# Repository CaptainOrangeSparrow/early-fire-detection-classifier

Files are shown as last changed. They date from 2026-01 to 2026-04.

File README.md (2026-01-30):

# Early-fire-detection-classifier

## Description

This repository aims to detect fires at an early stage and classify the type of fire using sensor-fusion techniques and machine learning. The project is from the University of Texas at Austin's engineering senior design group Spring 2026.

## Things that are Good to Know

### GIT

Git on the jetson is setup using the SSH key route. Any git actions will not prompt a log in due to the stored SSH deploy key. Pushes will be recorded as have been made by the deploy key. Whoever is registered on the jetson's git config global user.email will show up as the user responsible of a commit at the time of commit.

To change the git config global user:

```git config --global user.email [git email here]```

When you want to do a COMMIT, change the git config global user email to your git email or sign your first name at the end of your commit message (For example add file -firstname).

Once you attempt to PUSH your changes, you will then be prompted with the following message to provide a passphrase for security (this passphrase is shared among the team members):

```Enter passphrase for key '/home/firedistinguisher/.ssh/id_ed25519':```

AFTER you finish pushing your changes and making edits, consider running the following command to clear the user.email environment variable so the next developer will be automatically reminded to provide their email when making their commits, thanks!

```git config --global --unset user.email```

-----

### SSH

To log onto the jetson from the ECE-LRC servers:

```ssh firedistinguisher@localhost -p 2000```

To log onto the jetson from the ECE-LRC servers with video forwarding:

```ssh firedistinguisher@localhost -p 2000 -Y```

To log onto the jetson from your laptop through the ECE-LRC servers to support web-streaming from local host on the jeston to your local browser:

```ssh ssh -J eid@mario.ece.utexas.edu -p 2000 firedistinguisher@localhost -L [port]:localhost:[port]```

- Replace [port] with the port number the web stream is hosted on or streaming to

-----

### CONDA Virtual Environment Manager

Available CONDA environments:

- base
- app
- appgui
- cameragui
- recording
- telemetry

Please do not modify the base environment.

-----

## Repository Structure

**I2C-testing**

This folder contains code to test accessing read-write functionality on the I2C bus using python smbus2 module for various connected devices including the ADC and HDC. Use i2cdetect -r to scan I2C busses for connected devices.

- ```basic-I2C.py``` sends read and write commands on the i2c bus
- ```ads1115-i2c.py``` is a class that reads values from the ads1115 modules
- ```hdc3022.py``` is a class that reads values from the hdc3022 temp and humidity sensor

Requires ```recording``` conda env.

-----

**audio-testing**

This folder contains code for testing the MAX98357A Audio Amp for producing audio from the jetson using the I2S protocol. 

- ```play-tone.py``` plays a sine wave for a specified duration and frequency
- ```play-wav.py``` plays a wav file

Requires ```recording``` conda env.

-----

**camera-gui**

This folder contains original python gui that was developed to play prerecorded mp4 files. A pyside 6 gui application is used to display the videos and interactive buttons.

- ```camera_gui.ipynb``` is the original python notebook that was used to develop the initial gui
- ```camera_gui.py``` is the python version of the ipynb notebook  
- ```test.txt``` is a test file

Requires ```cameragui``` conda env.

-----

**camera-testing**

This folder contains tools to view the raw camera streams for RGB and IR cameras. In particular, it contains code for the tc001. The raw camera streams open native openCV windows or host a web stream. NOTE: The tc001 code came from another repo leswright pythermalcam and contains some erroneous temperature decoding code. (That is fixed in the data recording camera module)

- ```readme```: This folder comes with its own readme. See readme for more details
- ```web-stream-camera.py``` is the web stream version of stream-camera.py. Note: to use the web-stream, the ssh port forwarding needs to be used. (See web stream ssh command above).

Requires ```cameragui``` conda env.

-----

**data-recording**

This is the main data recording software folder. Multi-modal data is recorded and streamed using either a pyside6 gui application, console only mode, or web stream application (recommended). Data is recorded at a default 25 FPS.

Recordings are saved to saved_recordings [dir] and test_recordings [dir] hold recordings that were taken just for testing and are kept for historical purposes.

- ```readme.txt```: This folder comes with its own readme. See readme for more details
- ```record.py``` is the main data recording script```
- ```utilities``` [dir] holds utility modules such as writers, web stream host server, html, javascript, etc. and other helpful utility code
- ```peripherals``` [dir] holds modules containing classes to read info and interact with connected external devices such as cameras and adcs.
- ```saved_recordings``` [dir] holds saved recordings
- ```test_recordings``` [dir] holds test recordings
- ```clear_Saved_to_test.py``` is a helper script to move all recordings in saved_recordings to test_recordings
- ```gstreamer_test.py``` is a helper script to test using gstreamer to run nvidia hardware optimized camera frames
- ```verify-frame-count.py``` is a helper script to count the number of frames in every mp4 file in a specified directory (does not search child directories)

Requires ```recording``` conda env.

-----

**downloads**

The purpose of this folder is to store files in transit (Files that needed to be copied over into or exported out of the jeston).

-----

**stream-camera-gui**

This folder contains files to stream both RGB and IR camera feeds simultaneously with a more custom gui in a pyside6 application

- ```readme.txt```: This folder comes with its own readme. See readme for more details. This readme has details for the rest of the components in the folder and therefore the other contents in the folder won't be listed again here.

Requires ```appgui``` conda env.

-----

**telemetry-display**

This folder contains files to stream data to a ST7735 LCD display.

Requires ```telemetry``` conda env.

-----

**test-files**

This folder contains miscellaneous test files.

----

## Additional Notes

Thanks, add anything other considerations here if need be.

Michael

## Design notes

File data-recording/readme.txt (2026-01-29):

===================
Readme.txt

record.py is the main recording script. 
Activate the conda env named recording.
Do python record.py -h for more details about its params

Note: If --web-preview is used, to view the web app on your local browser at localhost:5000, 
	you need to have ssh-ed in with the following or open another terminal and do another ssh:

	ssh -J eid@mario.ece.utexas.edu -p 2000 firedistinguisher@localhost -L 5000:localhost:5000 -Y

	If you get a bunch of channel open failed, that is the browser trying to connect when the script
	is not running. So when not using the script, close the browser tab if you want to remove that message.

Recommended use: python record.py [name] --no-gui --web-preview (--view-only if not recording)

You can change whether the thermal camera frames use Min-Max Normalization or Fixed Ranged Normalization by changing
a setting on Line 147 in peripherals/cameras.py

Directories:
- saved_recordings[dir] is the default location that new recordings are saved.
- peripherals[dir] and utilities[dir] are extra helper python modules to help record.py function

Recordings are saved in the following format:
- New directory created and named appropriately
- .mp4 for rgb camera
- .mp4 for ir camera
- .csv for all channels of the ADC
- .json to hold metadatda
- .npz files for raw thermal data (stored in raw_ir [directory])

- The rows of the csv file should match up with the frames of the mp4 files
- The new directory created will have the name, desired fps, date, index, unix time, and time.
  The index increments when there is a recording with the same date in the same destination directory
- The arrays in the npz files store the raw 192x256 data in row major order (top left corner is 0,0, +y axis down, +x axis right). Frame number is also stored along with the arrays

Other scripts:
- clear_saved_to_test.py is a script that moves all the recordings in the saved_recordings directory into the test_recordings directory.
- gstreamer-test.py is a script to test gstreamer pipelines when opening camera devices with python scripts.
- verify-frame-count.py counts the number of frames of all .mp4 files in a given directory.

-Michael

===================

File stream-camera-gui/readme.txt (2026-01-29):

===================

constants.py
- file to store global constants for easy access and so it is also accessible from all other modules/files

gui.py
- integrated IR camera stream with Moby's original gui

gui-new.py
- integrated both IR and RGB camera streams with a new gui layout

peripherals [dir]
- folder containing python modules to inteface sensors with the gui

	cameras.py
	- contains classes for RBG and IR cameras to be intialized and used elsewhere with functions to read frames.
	  supports multiple things accessing it at once.

gui-assets [dir]
- folder containing resources to support the gui such as downloaded fonts, images, etc.

saved_recordings [dir]
- folder containing saved recordings to be played back in the gui.
  future recordings could be saved here from the gui.

===================

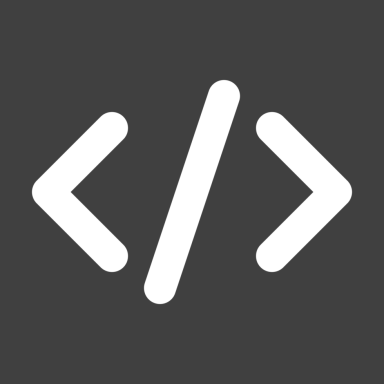
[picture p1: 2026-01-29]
stream-camera-gui/gui-assets/images/Nav-Code.png

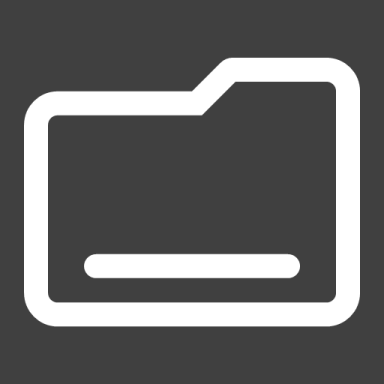
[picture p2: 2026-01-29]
stream-camera-gui/gui-assets/images/Nav-Saves.png

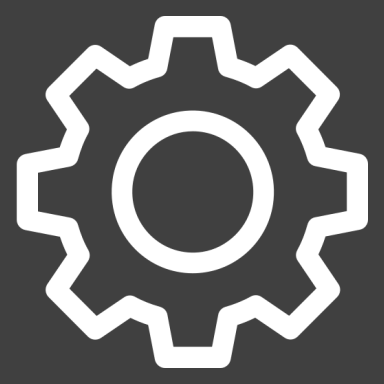
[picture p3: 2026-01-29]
stream-camera-gui/gui-assets/images/Nav-Settings.png

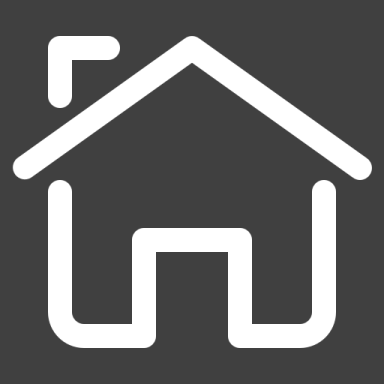
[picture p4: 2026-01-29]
stream-camera-gui/gui-assets/images/Nav-Home.png

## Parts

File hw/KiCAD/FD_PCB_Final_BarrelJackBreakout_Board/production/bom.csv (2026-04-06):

Designator | Footprint | Quantity | Value | LCSC Part #
H3, H4, H5, H6 | MountingHole_4_40 | 4 | ~
J1 | BarrelJack_Wuerth_6941xx301002 | 1 | Barrel_Jack_Switch
J24 | PinHeader_1x02_P2.54mm_Vertical | 1 | Conn_01x02

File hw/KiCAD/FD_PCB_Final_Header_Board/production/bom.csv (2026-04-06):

Designator | Footprint | Quantity | Value | LCSC Part #
C1, C2, C3 | CP_Radial_Tantal200mil | 3 | 220u
C16 | C_Axial_200mil | 1 | 10u
C17, C18, C19, C20 | 0805 | 4 | 0.1u
C6 | CP_Radial_Tantal200mil | 1 | 47u
H17, H18, H19, H20 | MountingHole_4_40 | 4 | ~
J10, J11, J25, J7 | PinHeader_1x02_P2.54mm_Vertical | 4 | Conn_01x02
J12 | JST_PH_B2B-PH-K_1x02_P2.00mm_Vertical | 1 | Conn_01x02
J2 | PinHeader_2x12_P2.54mm_Vertical | 1 | Conn_02x12_Odd_Even
J4 | PinHeader_2x20_P2.54mm_Vertical | 1 | Conn_02x20_Odd_Even
J5 | PinHeader_2x10_P2.54mm_Vertical | 1 | Conn_02x10_Odd_Even
J6 | PinHeader_1x07_P2.54mm_Vertical | 1 | Conn_01x07
M1, M2 | PinHeader_1x03_P2.54mm_Vertical | 2 | Motor_Servo
R2 | 0805 | 1 | 100k
TP11, TP4, TP8 | TestPoint_Loop_D3.50mm_Drill1.4mm_Beaded | 3 | TestPoint

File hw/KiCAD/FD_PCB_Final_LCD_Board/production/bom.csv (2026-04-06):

Designator | Footprint | Quantity | Value | LCSC Part #
H10, H7, H8, H9 | MountingHole_4_40 | 4 | ~
J3 | PinHeader_2x12_P2.54mm_Vertical | 1 | Conn_02x12_Odd_Even
J9 | PinHeader_1x16_P2.54mm_Vertical | 1 | Conn_01x16
R1, R3, R4 | 0805 | 3 | 1k
SW1, SW2, SW3 | SW_PUSH_6mm | 3 | SW_Push
TP1, TP10, TP12, TP13, TP14, TP2, TP3, TP46, TP5, TP6, TP7, TP9 | TestPoint_Loop_D3.50mm_Drill1.4mm_Beaded | 12 | TestPoint

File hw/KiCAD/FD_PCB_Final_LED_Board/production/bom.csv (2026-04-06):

Designator | Footprint | Quantity | Value | LCSC Part #
D1 | LED_D5.0mm | 1 | +5V PWR
D2 | LED_D5.0mm | 1 | +3V3 PWR
D3 | LED_D5.0mm | 1 | LED_1
D4 | LED_D5.0mm | 1 | LED_2
H1, H2 | MountingHole_4_40 | 2 | ~
J21 | PinHeader_1x08_P2.54mm_Vertical | 1 | Conn_01x08

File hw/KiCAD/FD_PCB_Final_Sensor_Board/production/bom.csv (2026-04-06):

Designator | Footprint | Quantity | Value | LCSC Part #
C10, C11, C12, C13, C14, C15, C7, C8 | 0805 | 8 | 1u
C21, C4, C5 | CP_Radial_Tantal200mil | 3 | 4.7u
C9 | CP_Radial_Tantal200mil | 1 | 47u
D5 | LED_D5.0mm | 1 | +5V PWR
D6 | LED_D5.0mm | 1 | +3V3 PWR
FB1, FB2, FB3, FB4 | 0603 | 4 | FerriteBead
H11, H12, H13, H14, H15, H16 | MountingHole_4_40 | 6 | ~
J13 | PinHeader_2x10_P2.54mm_Vertical | 1 | Conn_02x10_Odd_Even
J14 | PinHeader_1x04_P2.54mm_Vertical | 1 | MQ-4 Gas Sensor
J15 | PinHeader_1x04_P2.54mm_Vertical | 1 | MQ-7 Gas Sensor
J16 | PinHeader_1x04_P2.54mm_Vertical | 1 | MQ-138 Gas Sensor
J17 | PinHeader_1x04_P2.54mm_Vertical | 1 | KY-026 Flame Sensor
J18 | PinHeader_1x10_P2.00mm_Vertical | 1 | Conn_01x10
J19 | PinHeader_1x05_P2.00mm_Vertical | 1 | Conn_01x05
J20 | PinHeader_1x06_P2.54mm_Vertical | 1 | HDC3022
J22 | PinHeader_1x05_P2.54mm_Vertical | 1 | MiCS-6814
J23 | PinHeader_1x02_P2.54mm_Vertical | 1 | Conn_01x02
J8 | PinHeader_1x08_P2.54mm_Vertical | 1 | Conn_01x08
R10, R11, R22, R23, R24, R9 | 0805 | 6 | 18k
R12, R13, R14, R25, R26, R27 | 0805 | 6 | 33k
R15, R16, R17, R18, R28, R29, R30, R31 | 0805 | 8 | 10k
R19 | 0805 | 1 | 560k
R20 | 0805 | 1 | 150k
R21 | 0805 | 1 | 15k
R32, R33 | 0805 | 2 | 0
R34, R7 | 0805 | 2 | 2k
R35, R6, R8 | 0805 | 3 | 1k
R5 | 0805 | 1 | 330
TP15, TP16, TP17, TP18, TP19, TP20, TP21, TP22, TP23, TP24, TP25, TP26, TP27, TP28, TP29, TP30, TP31, TP32, TP33, TP34, TP35, TP36, TP37, TP38, TP39, TP40, TP41, TP42, TP43, TP44, TP45 | TestPoint_Loop_D3.50mm_Drill1.4mm_Beaded | 31 | TestPoint
U1, U4 | TSSOP-10_3x3mm_P0.5mm | 2 | ADS1115IDGS
U2, U3 | DIP-8_W7.62mm_LongPads | 2 | OPA2350

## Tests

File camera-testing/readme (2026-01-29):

===================
tc001 [dir]
- Code to view TC001 camera

stream-camera.py
- stream any video device to an opencv window

venv [dir]
- Python virtual environment

===================

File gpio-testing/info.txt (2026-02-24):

(recording) firedistinguisher@jetsonnano:~/projects/early-fire-detection-classifier/gpio-testing$ sudo -E /home/firedistinguisher/miniconda3/envs/recording/bin/python jetson-gpio.py
/home/firedistinguisher/miniconda3/envs/recording/lib/python3.10/site-packages/Jetson/GPIO/gpio_cdev.py:361: UserWarning:
[WARNING] User requested output for channel "15", but it is set to input in pinmux. For more information on resolving this, please see
https://docs.nvidia.com/jetson/archives/r36.3/DeveloperGuide/HR/JetsonModuleAdaptationAndBringUp/JetsonOrinNxNanoSeries.html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

This can be resolved *temporarily* (until next restart) by running:
    sudo busybox devmem 0x2440020 w 0x5

  warnings.warn(

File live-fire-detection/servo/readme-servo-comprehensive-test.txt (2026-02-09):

# Run all tests
python3 servo-comprehensive-test.py

# Run specific test suite
python3 servo-comprehensive-test.py basic
python3 servo-comprehensive-test.py linear
python3 servo-comprehensive-test.py patterns

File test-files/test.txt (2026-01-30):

MC test 01-30-2026
MC test 01-30-2026 at 3:03am

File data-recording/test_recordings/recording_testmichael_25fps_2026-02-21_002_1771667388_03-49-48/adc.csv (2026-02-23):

frame_idx | t_sample_perf_counter | t_reg_frame | t_ir_frame | t_adc_sweep | adc_sweep_dt_s | adc0_ch0 | adc0_ch1 | adc0_ch2 | adc0_ch3 | adc1_ch0 | adc1_ch1 | adc1_ch2 | adc1_ch3 | ir_min | ir_max | ir_avg | ir_center | t_hdc_sample | hdc_temp | hdc_humidity | t_sen0219_sample | co2_ppm | t_ze07co_sample | co_ppm
0 | 6463.558493449 | 6463.533839089 | 6463.547695484 | 6463.551141031 | 0.034862 | 1606 | 1768 | 5457 | 24379 | -711 | -763 | -763 | 4267 | 27.725000000000023 | 36.35000000000002 | 28.524509684244833 | 28.225000000000023 | 6463.546819169 | 27.558175020981153 | 41.031509880216674 | 1771667391.322329283 | 526 | 1771667391.341055393 | 0.5
1 | 6463.588732046 | 6463.568426044 | 6463.547695484 | 6463.551141031 | 0.034862 | 1606 | 1768 | 5457 | 24379 | -711 | -763 | -763 | 4267 | 27.725000000000023 | 36.35000000000002 | 28.524509684244833 | 28.225000000000023 | 6463.578676632 | 27.536812390325778 | 41.03608758678568 | 1771667391.352990150 | 526 | 1771667391.373149633 | 0.5
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

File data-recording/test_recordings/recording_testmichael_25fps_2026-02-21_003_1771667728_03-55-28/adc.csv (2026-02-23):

frame_idx | t_sample_perf_counter | t_reg_frame | t_ir_frame | t_adc_sweep | adc_sweep_dt_s | adc0_ch0 | adc0_ch1 | adc0_ch2 | adc0_ch3 | adc1_ch0 | adc1_ch1 | adc1_ch2 | adc1_ch3 | ir_min | ir_max | ir_avg | ir_center | t_hdc_sample | hdc_temp | hdc_humidity | t_sen0219_sample | co2_ppm | t_ze07co_sample | co_ppm
0 | 6804.402423980 | 6804.381755624 | 6804.384136805 | 6804.385002660 | 0.031725 | 1651 | 1863 | 5503 | 24334 | -710 | -755 | -759 | 4394 | 25.412500000000023 | 33.10000000000002 | 26.90463790893557 | 27.225000000000023 | 6804.379380364 | 27.536812390325778 | 41.361104753185316 | 6804.377583918 | 534 | 6804.364221313 | 0.5
1 | 6804.453322949 | 6804.411479487 | 6804.426995689 | 6804.429996645 | 0.044958 | 1656 | 1869 | 5522 | 24369 | -712 | -764 | -765 | 4422 | 25.412500000000023 | 33.10000000000002 | 26.9053728739421 | 27.225000000000023 | 6804.431103012 | 27.536812390325778 | 41.361104753185316 | 6804.405732263 | 534 | 6804.402953931 | 0.5
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

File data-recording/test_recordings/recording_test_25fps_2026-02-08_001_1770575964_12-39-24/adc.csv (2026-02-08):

frame_idx | t_sample_perf_counter | t_reg_frame | t_ir_frame | t_adc_sweep | adc_sweep_dt_s | adc0_ch0 | adc0_ch1 | adc0_ch2 | adc0_ch3 | adc1_ch0 | adc1_ch1 | adc1_ch2 | adc1_ch3 | ir_min | ir_max | ir_avg | ir_center | hdc_temp | hdc_humidity
0 | 27962.986315563 | 27962.952133460 | 27962.978301277 | 27962.934848659 | 0.036480 | 2469 | 3185 | 6495 | 25611 | -161 | -176 | -181 | 4617 | 26.037500000000023 | 37.72500000000002 | 32.32694905598959 | 36.47500000000002 | 27962.979030931 | 29.811932555123207 | 43.96124208438239
1 | 27963.008805351 | 27962.986508273 | 27962.978301277 | 27962.993043539 | 0.058148 | 2471 | 3189 | 6505 | 25616 | -164 | -178 | -179 | 4612 | 26.037500000000023 | 37.72500000000002 | 32.32694905598959 | 36.47500000000002 | 27963.003830516 | 29.79056992446783 | 43.95208667124437
2 | 27963.053611290 | 27963.020980625 | 27963.017713072 | 27963.044436586 | 0.051330 | 2474 | 3189 | 6509 | 25627 | -175 | -173 | -178 | 4605 | 25.975000000000023 | 37.72500000000002 | 32.33729960123702 | 36.47500000000002 | 27963.035914924 | 29.811932555123207 | 43.947508964675364
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

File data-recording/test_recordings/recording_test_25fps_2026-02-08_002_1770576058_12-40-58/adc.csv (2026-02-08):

frame_idx | t_sample_perf_counter | t_reg_frame | t_ir_frame | t_adc_sweep | adc_sweep_dt_s | adc0_ch0 | adc0_ch1 | adc0_ch2 | adc0_ch3 | adc1_ch0 | adc1_ch1 | adc1_ch2 | adc1_ch3 | ir_min | ir_max | ir_avg | ir_center | hdc_temp | hdc_humidity
0 | 28056.960129481 | 28056.936664305 | 28056.931167950 | 28056.937265635 | 0.031993 | 2591 | 3398 | 6693 | 25854 | -172 | -177 | -182 | 4616 | 32.22500000000002 | 43.41250000000002 | 38.21861801147463 | 41.47500000000002 | 28056.940258524 | 29.83329518577858 | 44.83710994125277
1 | 28056.998672193 | 28056.967953042 | 28056.966692364 | 28056.975335789 | 0.038035 | 2590 | 3399 | 6696 | 25861 | -175 | -181 | -184 | 4611 | 32.22500000000002 | 43.41250000000002 | 38.220950063069665 | 41.47500000000002 | 28056.988160329 | 29.83329518577858 | 44.84321355001145
2 | 28057.026890374 | 28057.003495856 | 28057.005752531 | 28057.015128809 | 0.039745 | 2593 | 3400 | 6696 | 25863 | -167 | -180 | -183 | 4588 | 32.22500000000002 | 43.41250000000002 | 38.22927500406905 | 41.47500000000002 | 28057.020738032 | 29.811932555123207 | 44.855420767528805
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

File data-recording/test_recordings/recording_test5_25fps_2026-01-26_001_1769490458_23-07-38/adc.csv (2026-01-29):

frame_idx | t_sample_perf_counter | t_reg_frame | t_ir_frame | t_adc_sweep | adc_sweep_dt_s | adc0_ch0 | adc0_ch1 | adc0_ch2 | adc0_ch3 | adc1_ch0 | adc1_ch1 | adc1_ch2 | adc1_ch3 | ir_min | ir_max | ir_avg | ir_center
0 | 442818.211030183 | 442818.190247730 | 442818.180236602 | 442818.171502153 | 0.027324 | 1898 | 304 | 155 | 4710 | 4661 | 4365 | 4934 | 5110 | 27.100000000000023 | 40.72500000000002 | 32.4667793273926 | 32.60000000000002
1 | 442818.246832144 | 442818.225938651 | 442818.215313183 | 442818.208507449 | 0.036987 | 1896 | 307 | 503 | 4763 | 4716 | 4454 | 4418 | 5558 | 27.100000000000023 | 40.72500000000002 | 32.47111536661788 | 32.60000000000002
2 | 442818.282644058 | 442818.259110741 | 442818.254787677 | 442818.250575461 | 0.042018 | 1898 | 304 | 160 | 4693 | 4585 | 4819 | 5297 | 4654 | 26.975000000000023 | 40.72500000000002 | 32.47264887491866 | 32.60000000000002
3 | 442818.329053374 | 442818.290890920 | 442818.297281932 | 442818.293457558 | 0.042829 | 1896 | 306 | 470 | 4750 | 4730 | 4266 | 5281 | 4606 | 26.975000000000023 | 40.72500000000002 | 32.47873458862307 | 32.60000000000002
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

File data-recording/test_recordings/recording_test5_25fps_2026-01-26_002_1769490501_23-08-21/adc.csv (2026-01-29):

frame_idx | t_sample_perf_counter | t_reg_frame | t_ir_frame | t_adc_sweep | adc_sweep_dt_s | adc0_ch0 | adc0_ch1 | adc0_ch2 | adc0_ch3 | adc1_ch0 | adc1_ch1 | adc1_ch2 | adc1_ch3 | ir_min | ir_max | ir_avg | ir_center
0 | 442860.877039174 | 442860.863238310 | 442860.856792920 | 442860.862135710 | 0.032157 | 1901 | 307 | 75 | 4676 | 4719 | 5124 | 4641 | 4051 | 26.850000000000023 | 39.35000000000002 | 31.3154070536296 | 31.350000000000023
1 | 442860.910614833 | 442860.895155845 | 442860.890751302 | 442860.898824990 | 0.036654 | 1904 | 306 | 132 | 4739 | 4781 | 4745 | 3923 | 4788 | 26.850000000000023 | 39.41250000000002 | 31.32144444783529 | 31.287500000000023
2 | 442860.951321582 | 442860.931171905 | 442860.929185715 | 442860.938804406 | 0.039938 | 1902 | 305 | 410 | 4756 | 4651 | 4131 | 5147 | 4890 | 26.850000000000023 | 39.41250000000002 | 31.323936716715536 | 31.287500000000023
3 | 442860.993825687 | 442860.963849701 | 442860.969279051 | 442860.973593769 | 0.034756 | 1901 | 306 | 51 | 4707 | 4589 | 4659 | 5169 | 4676 | 26.850000000000023 | 39.35000000000002 | 31.325697835286462 | 31.350000000000023
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

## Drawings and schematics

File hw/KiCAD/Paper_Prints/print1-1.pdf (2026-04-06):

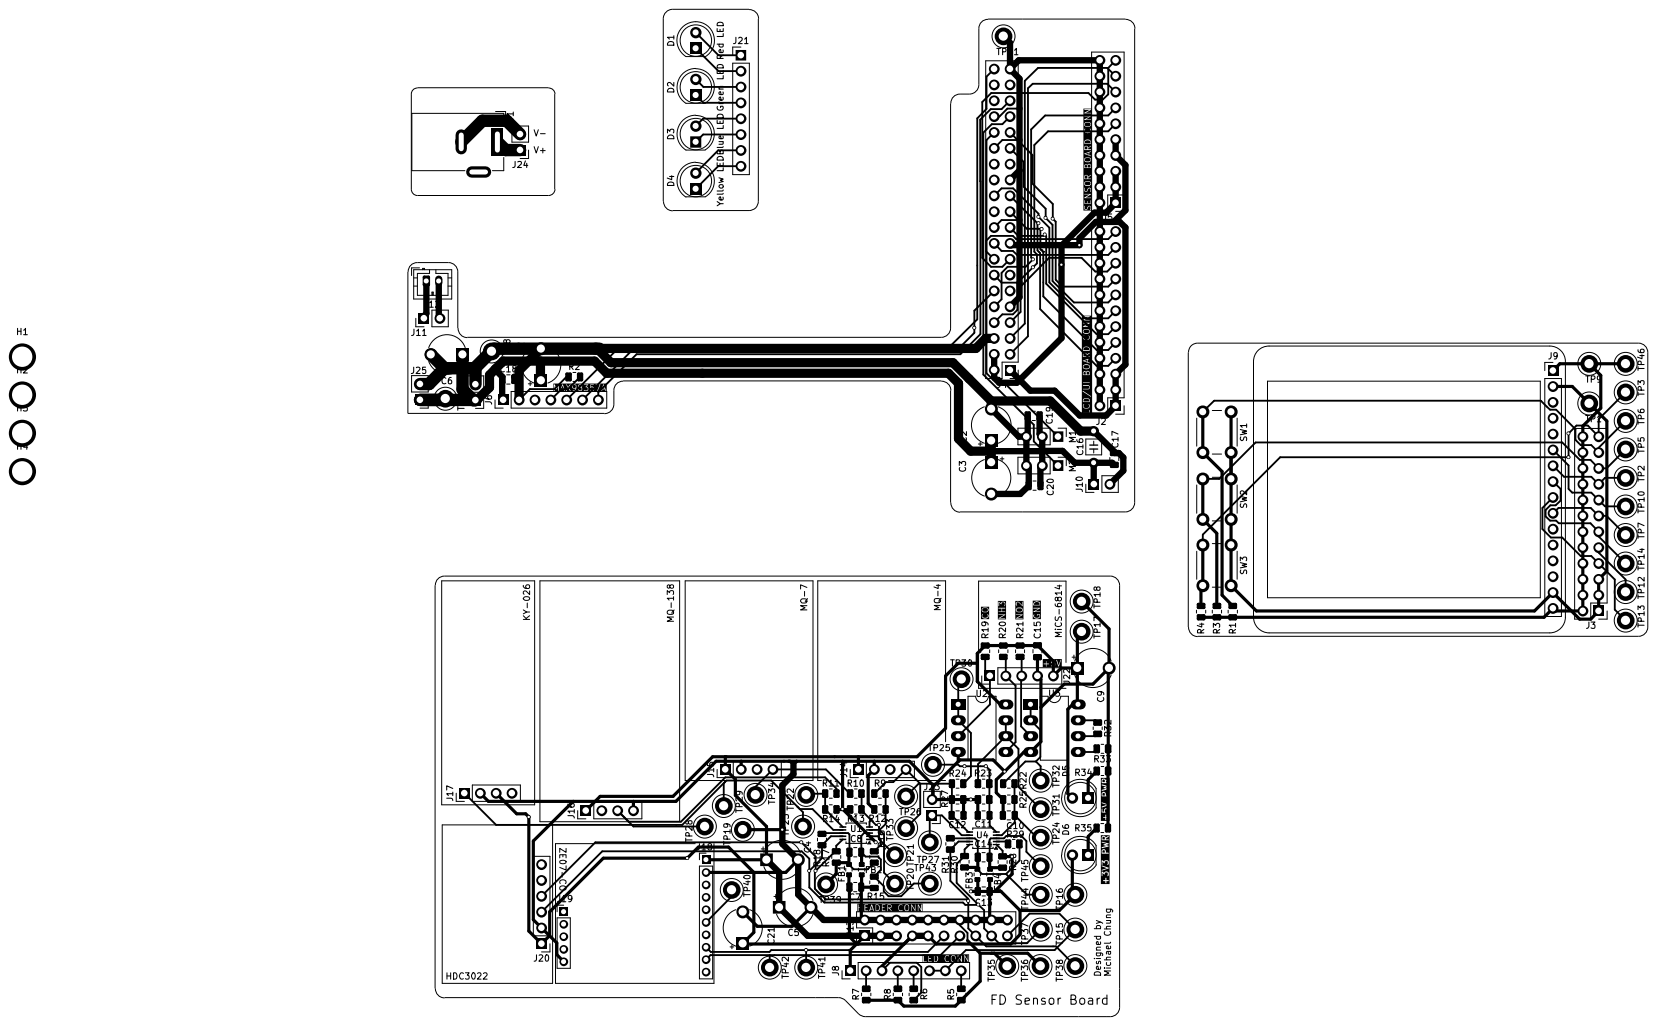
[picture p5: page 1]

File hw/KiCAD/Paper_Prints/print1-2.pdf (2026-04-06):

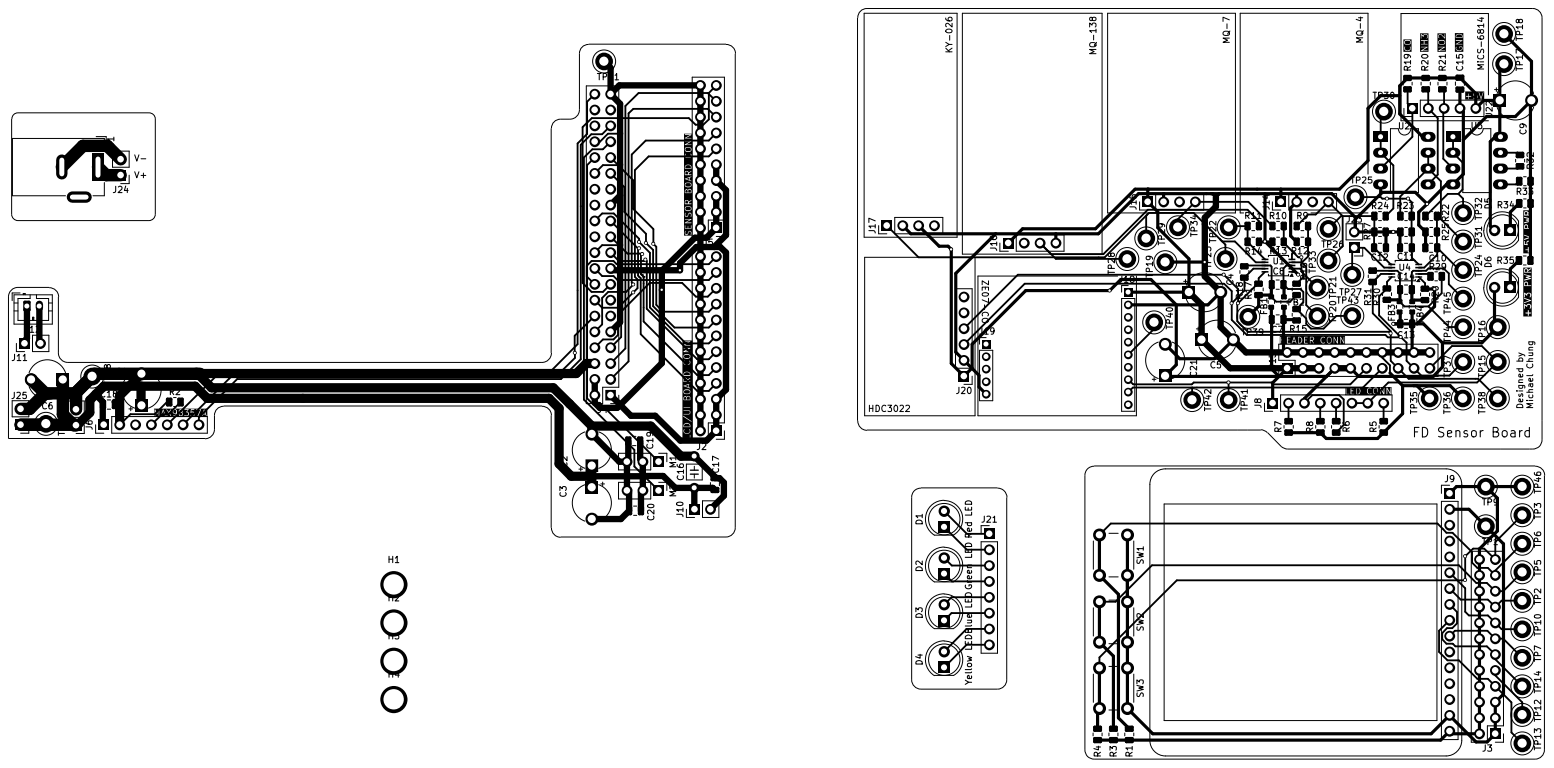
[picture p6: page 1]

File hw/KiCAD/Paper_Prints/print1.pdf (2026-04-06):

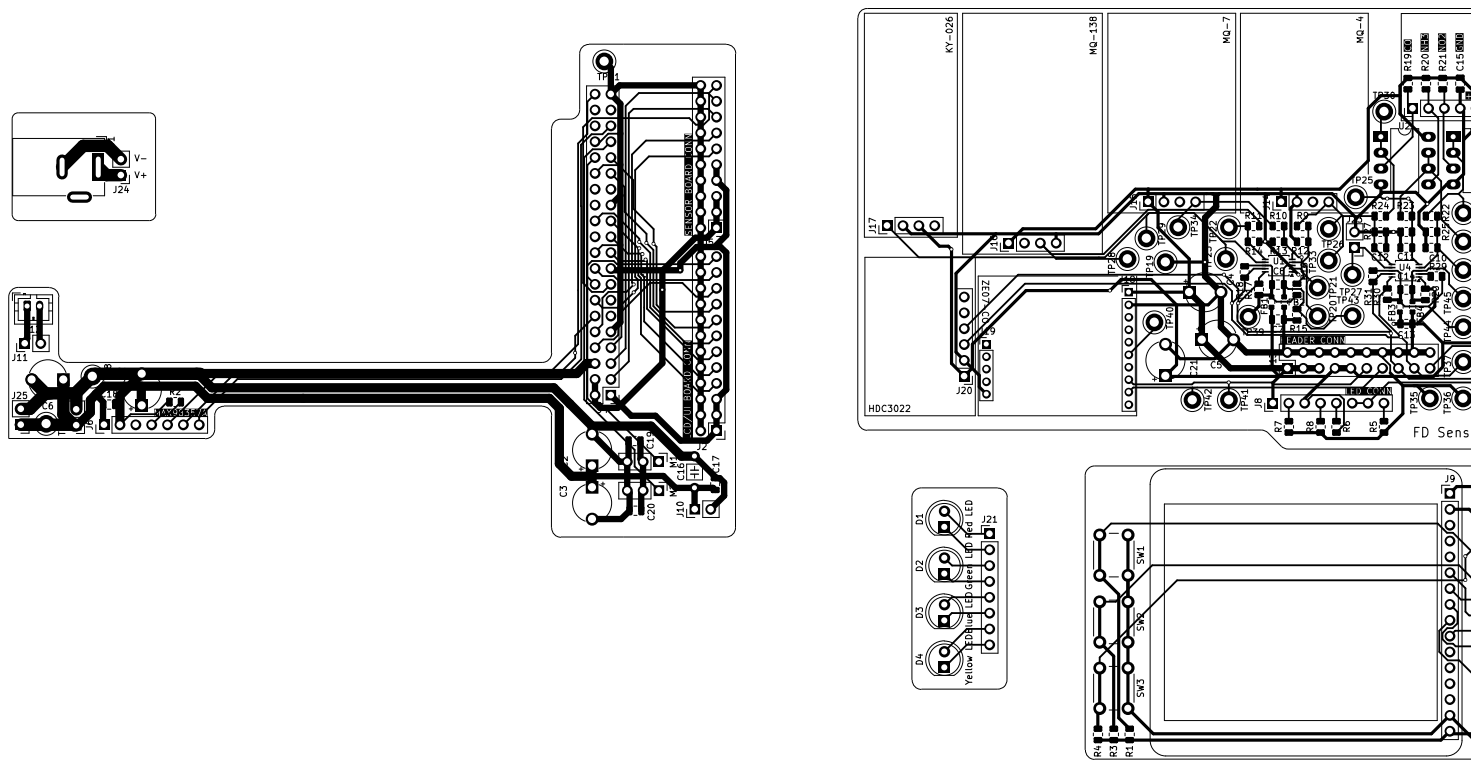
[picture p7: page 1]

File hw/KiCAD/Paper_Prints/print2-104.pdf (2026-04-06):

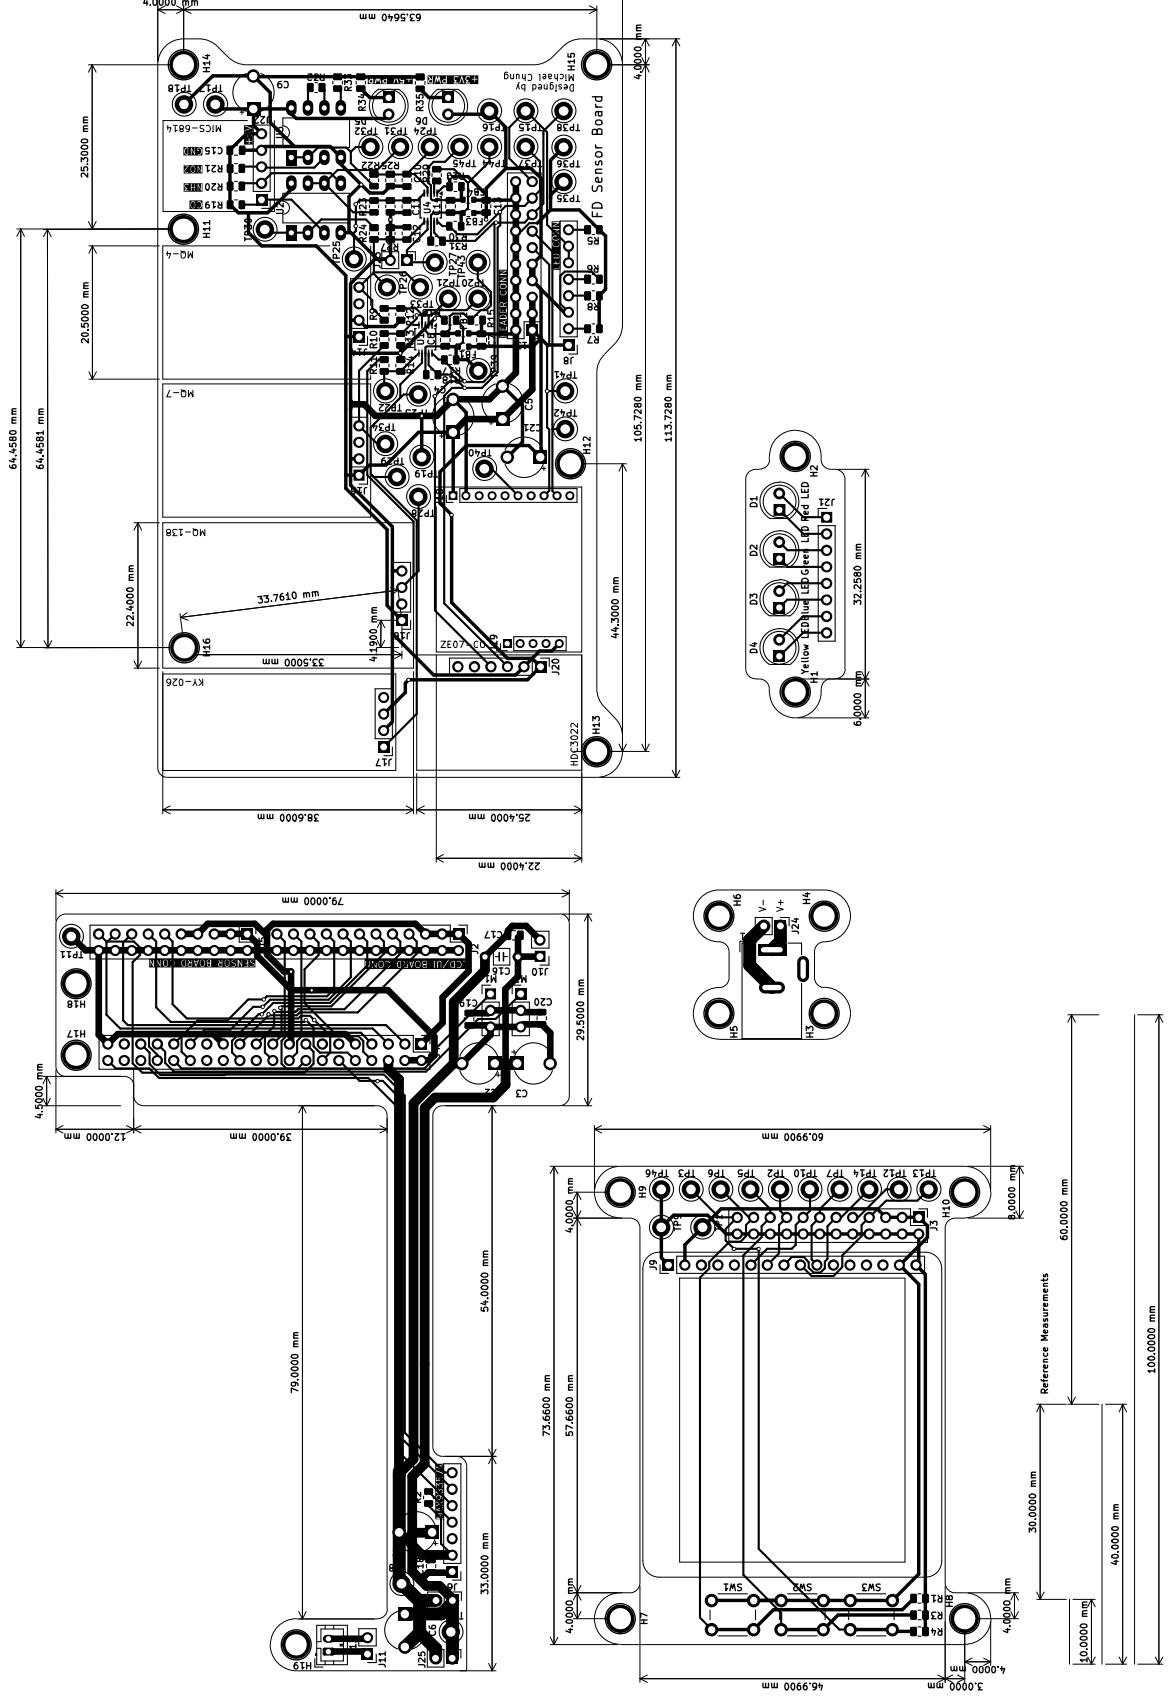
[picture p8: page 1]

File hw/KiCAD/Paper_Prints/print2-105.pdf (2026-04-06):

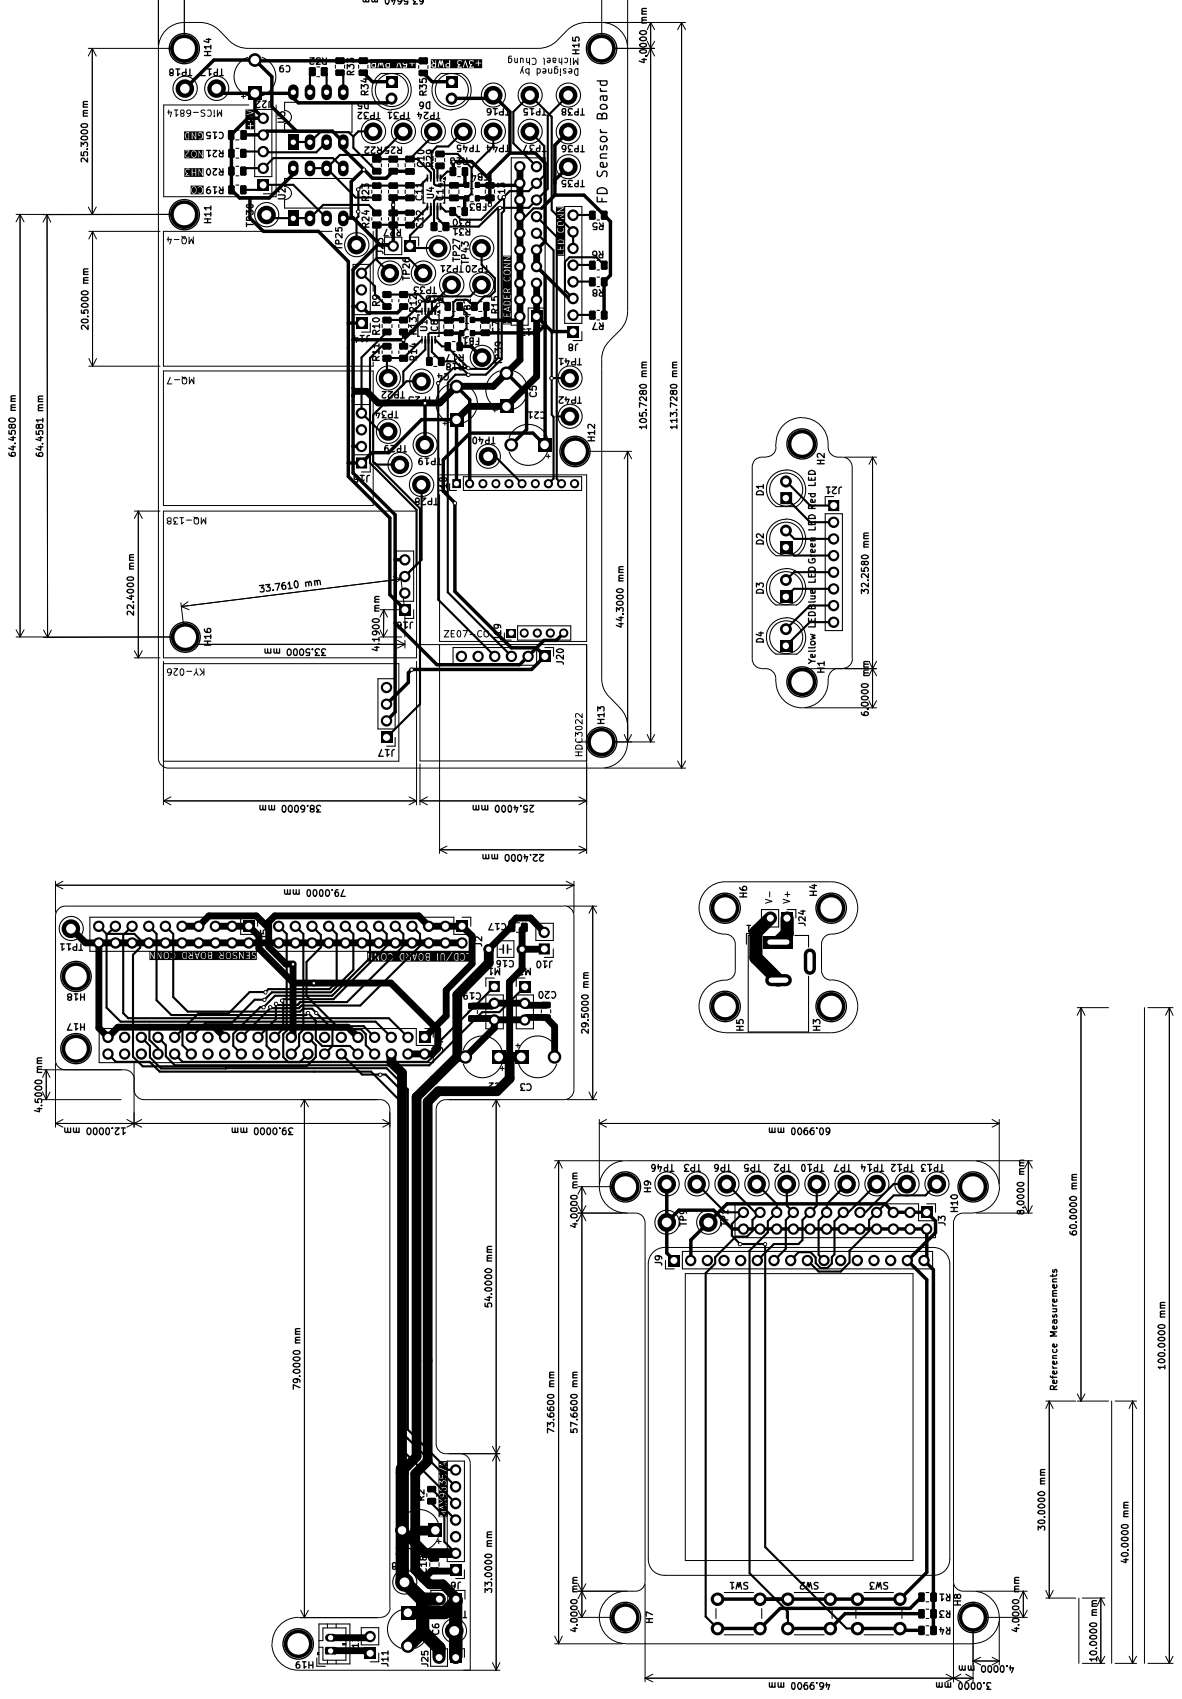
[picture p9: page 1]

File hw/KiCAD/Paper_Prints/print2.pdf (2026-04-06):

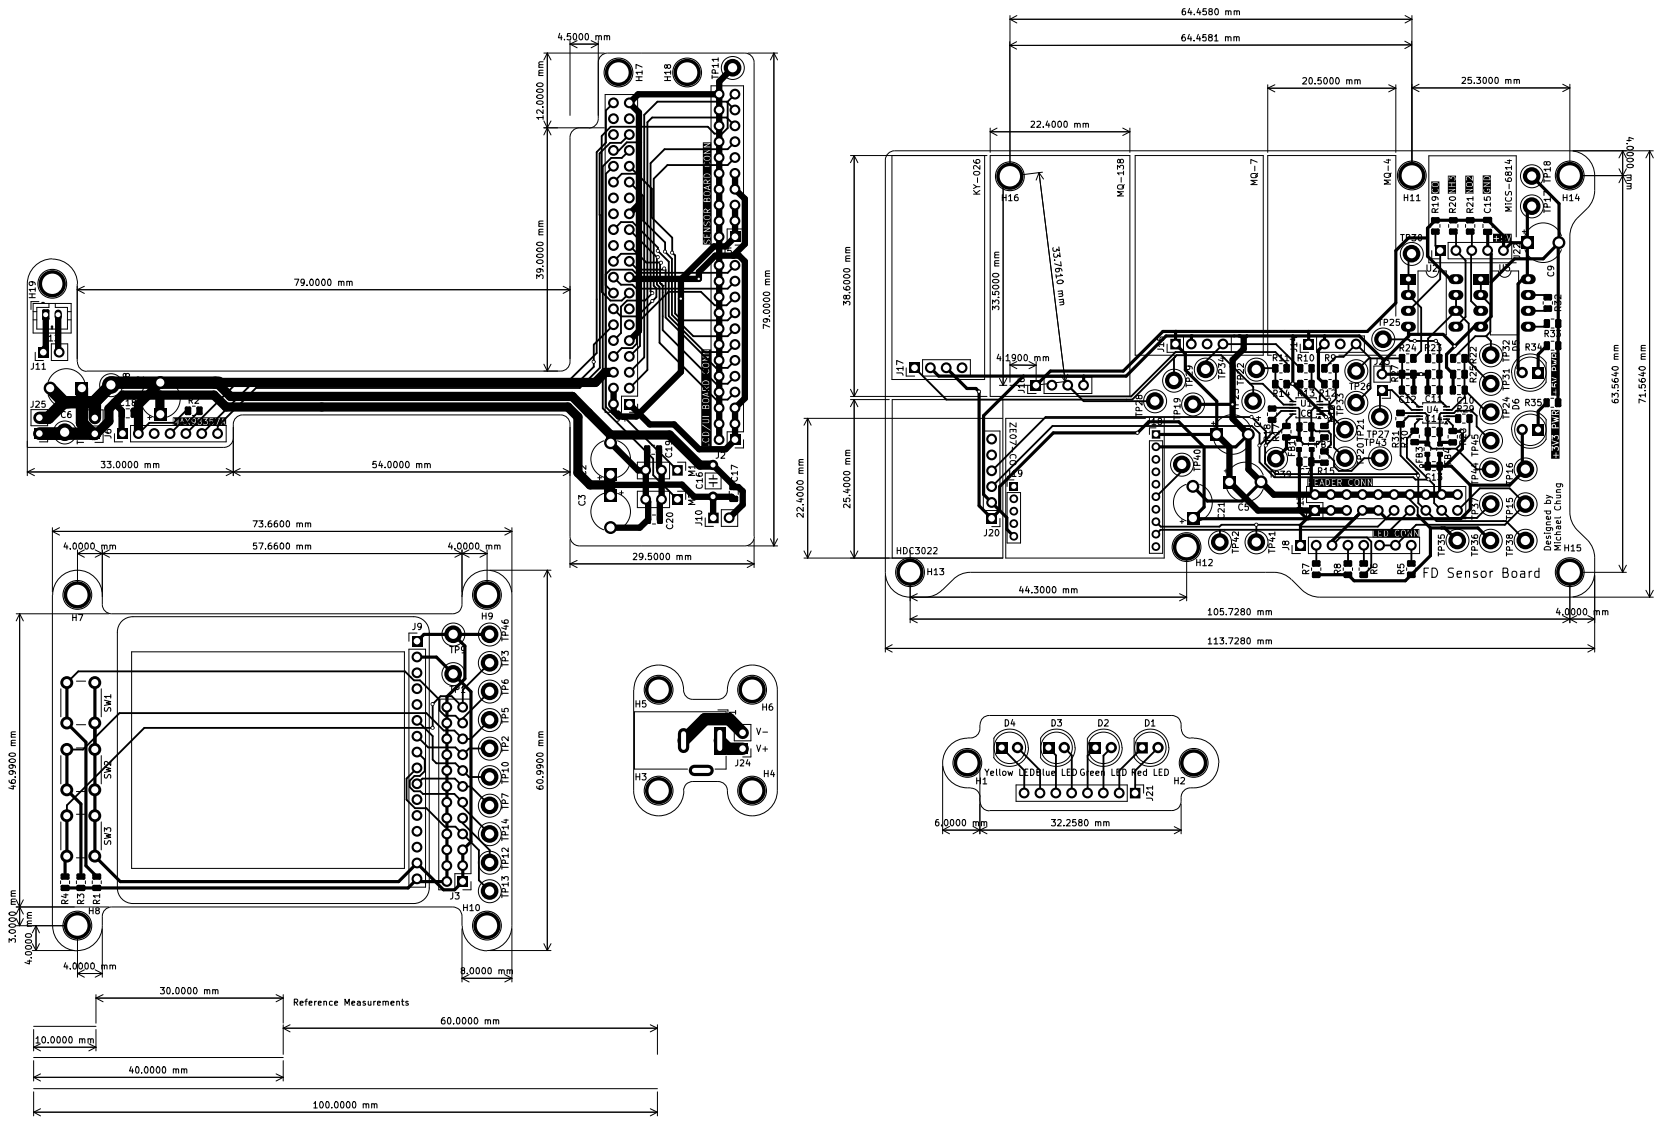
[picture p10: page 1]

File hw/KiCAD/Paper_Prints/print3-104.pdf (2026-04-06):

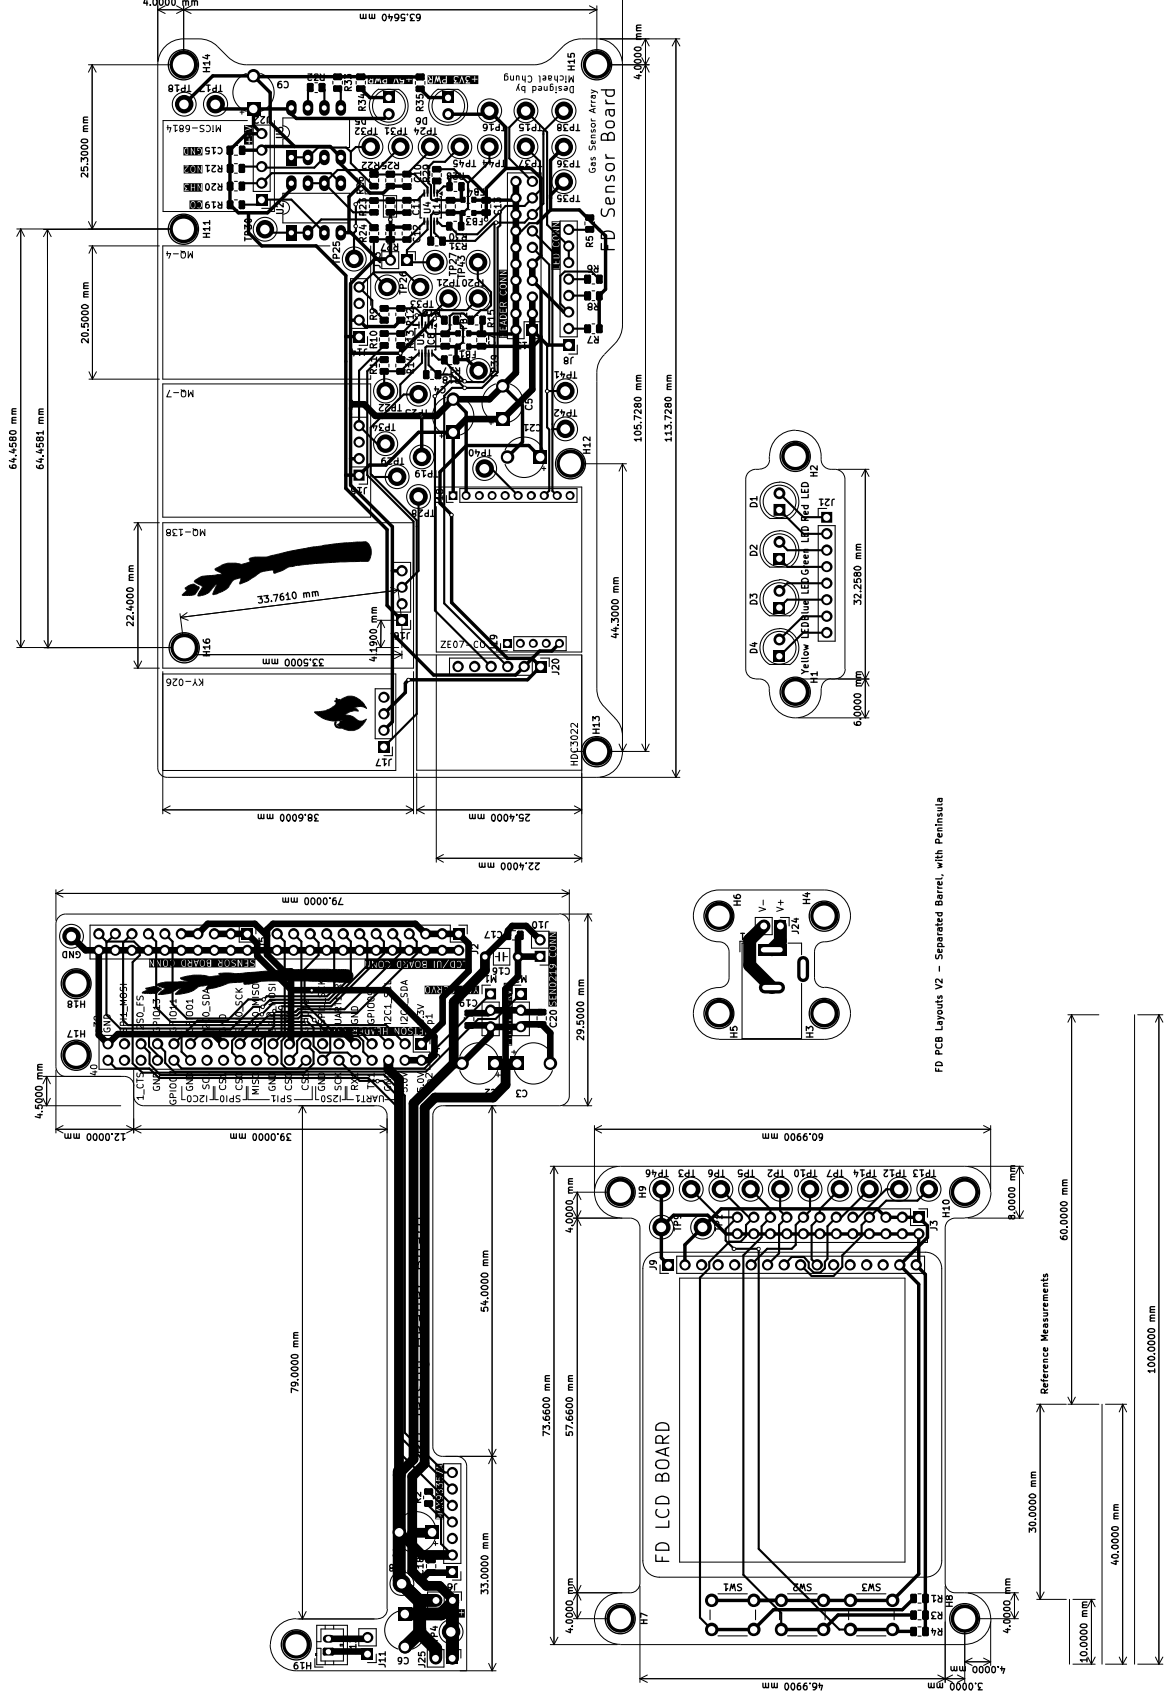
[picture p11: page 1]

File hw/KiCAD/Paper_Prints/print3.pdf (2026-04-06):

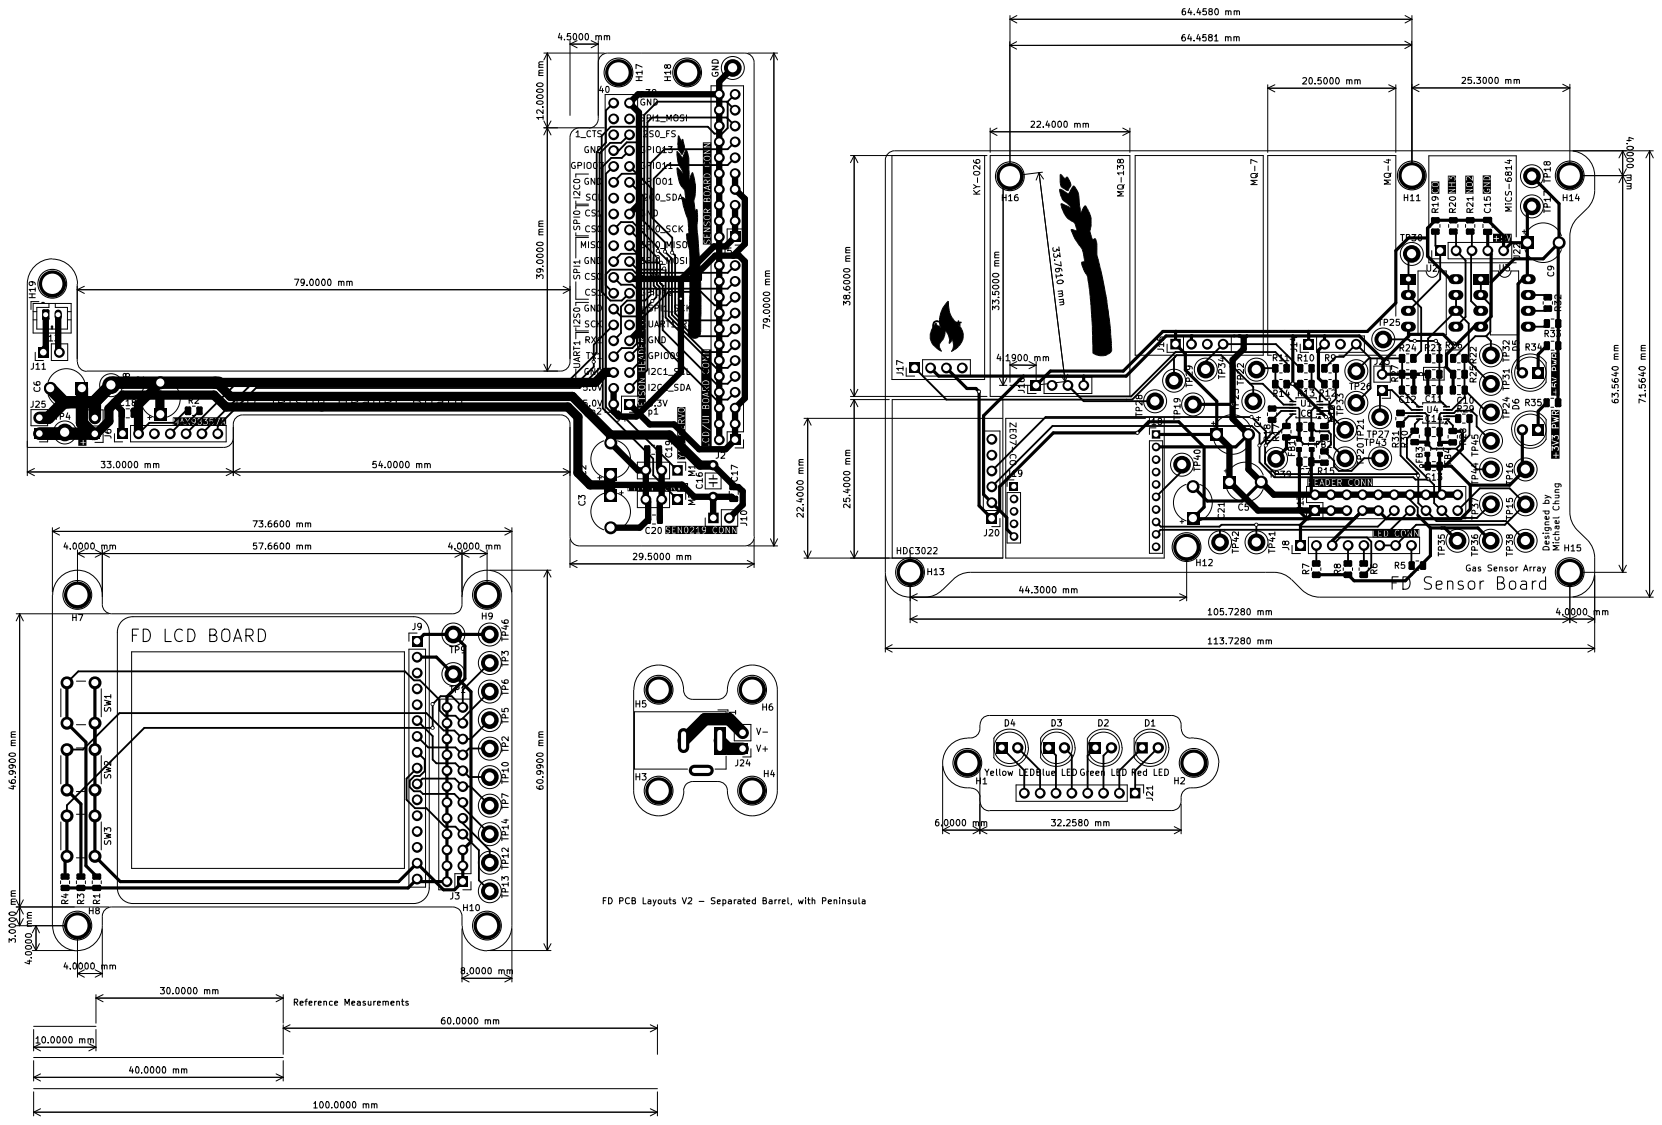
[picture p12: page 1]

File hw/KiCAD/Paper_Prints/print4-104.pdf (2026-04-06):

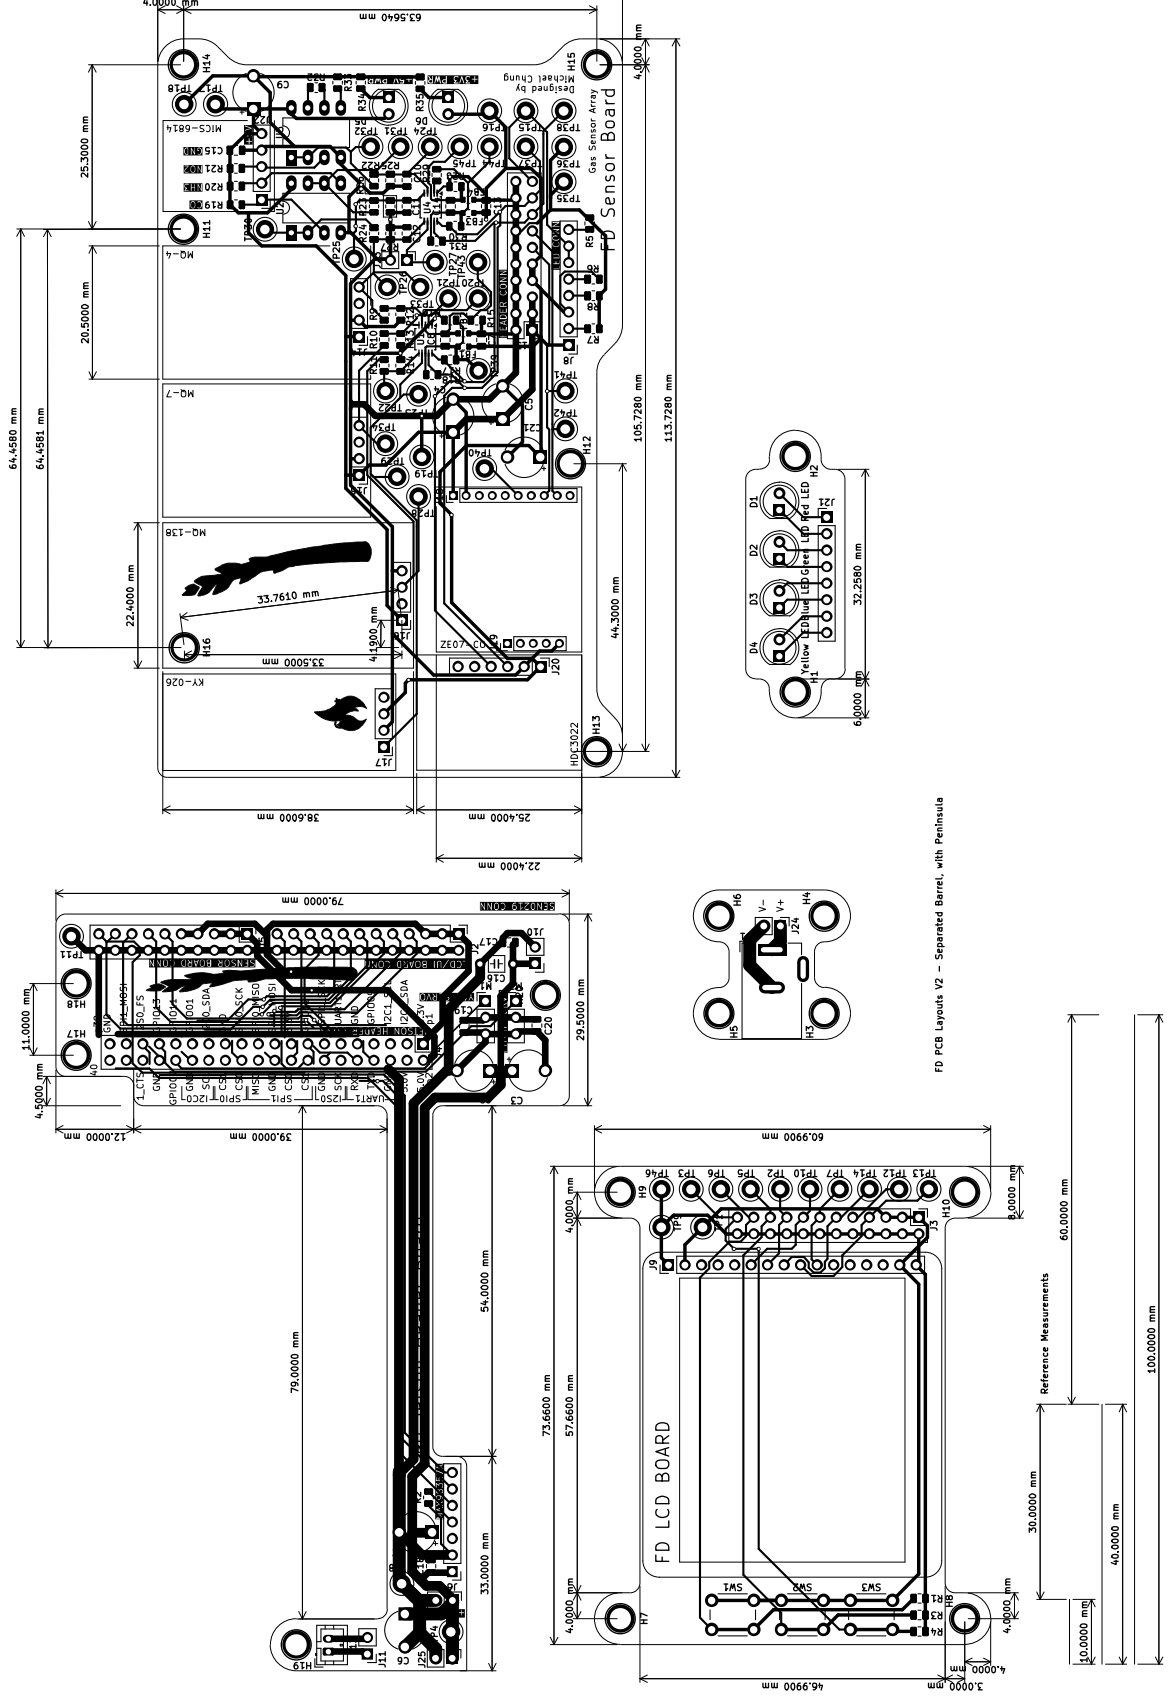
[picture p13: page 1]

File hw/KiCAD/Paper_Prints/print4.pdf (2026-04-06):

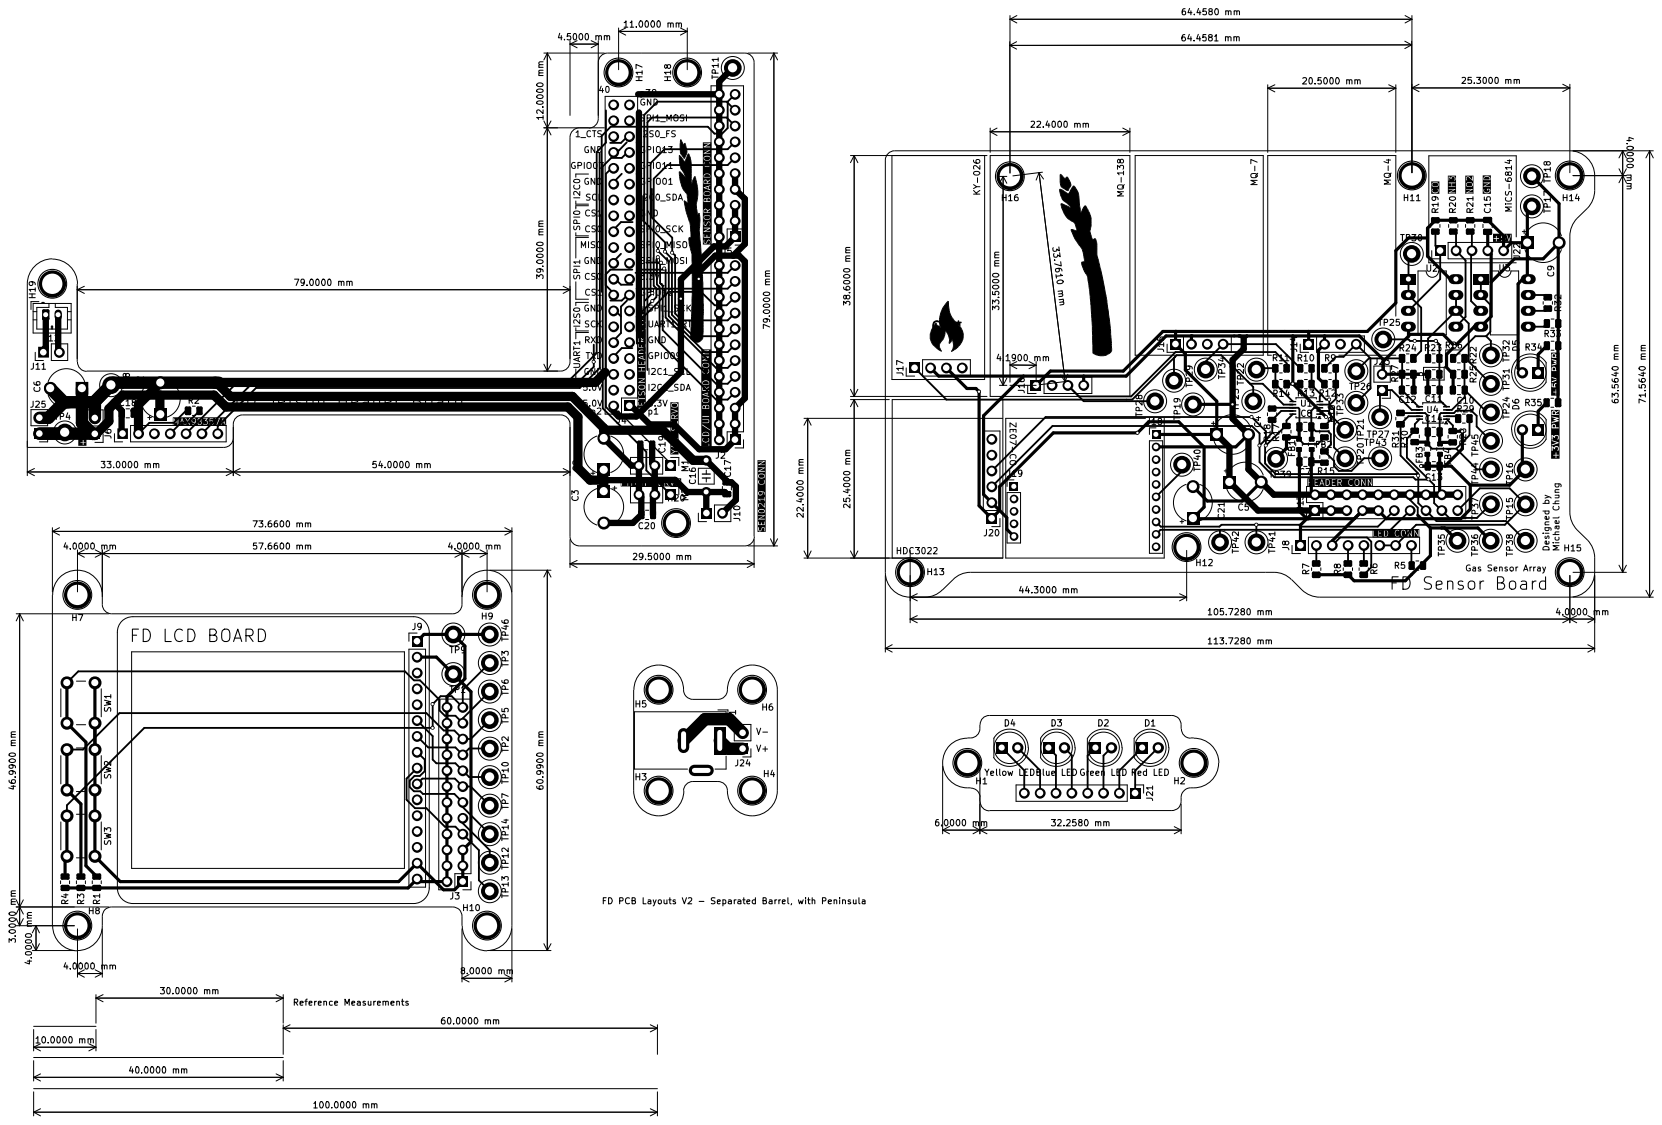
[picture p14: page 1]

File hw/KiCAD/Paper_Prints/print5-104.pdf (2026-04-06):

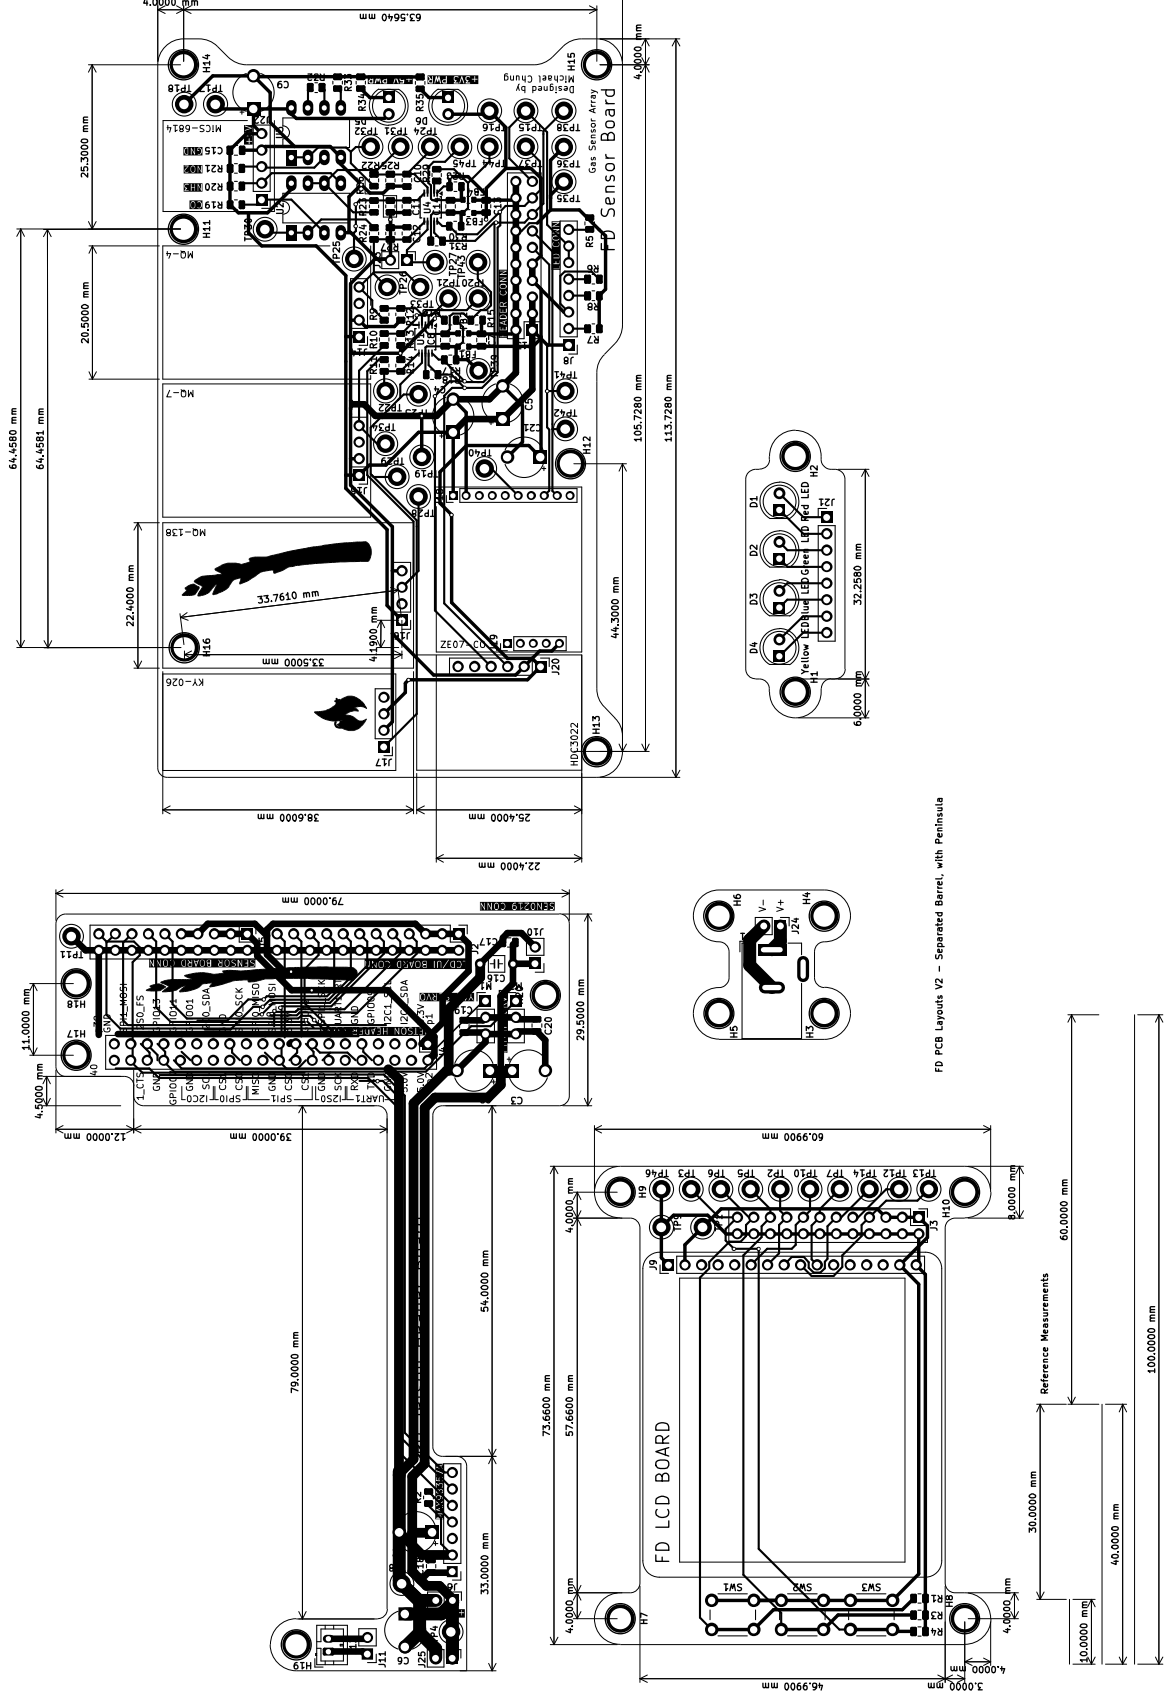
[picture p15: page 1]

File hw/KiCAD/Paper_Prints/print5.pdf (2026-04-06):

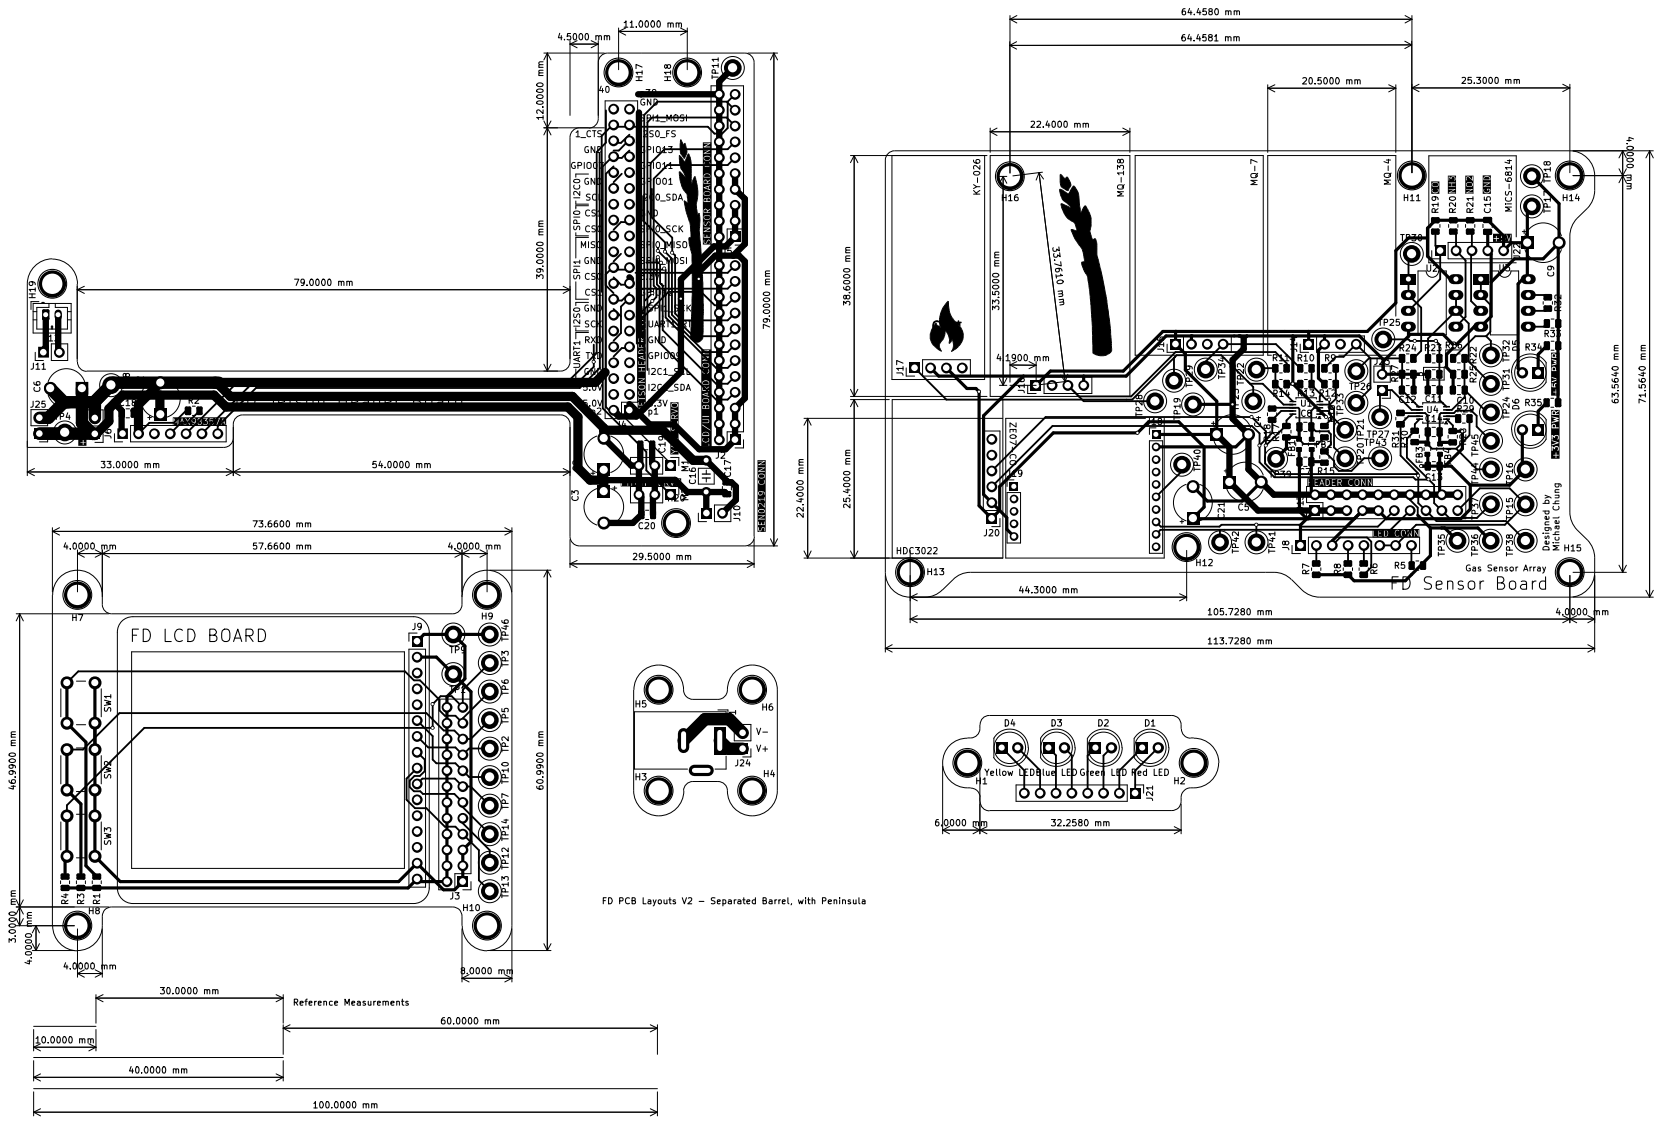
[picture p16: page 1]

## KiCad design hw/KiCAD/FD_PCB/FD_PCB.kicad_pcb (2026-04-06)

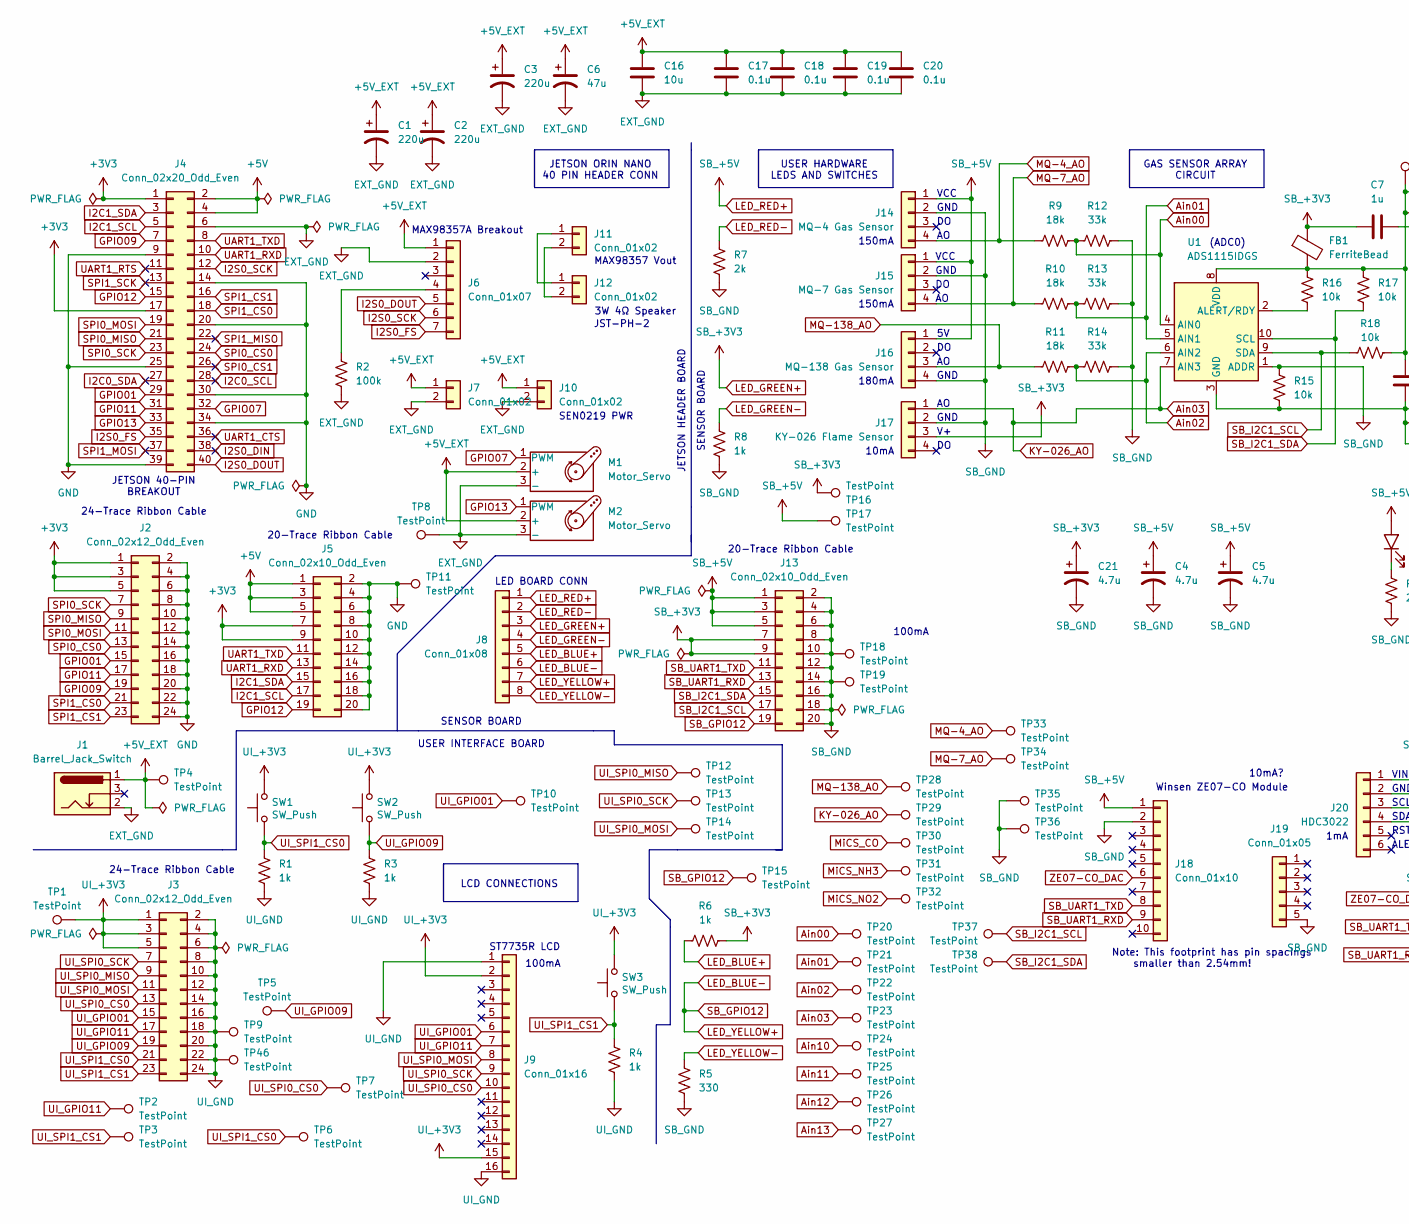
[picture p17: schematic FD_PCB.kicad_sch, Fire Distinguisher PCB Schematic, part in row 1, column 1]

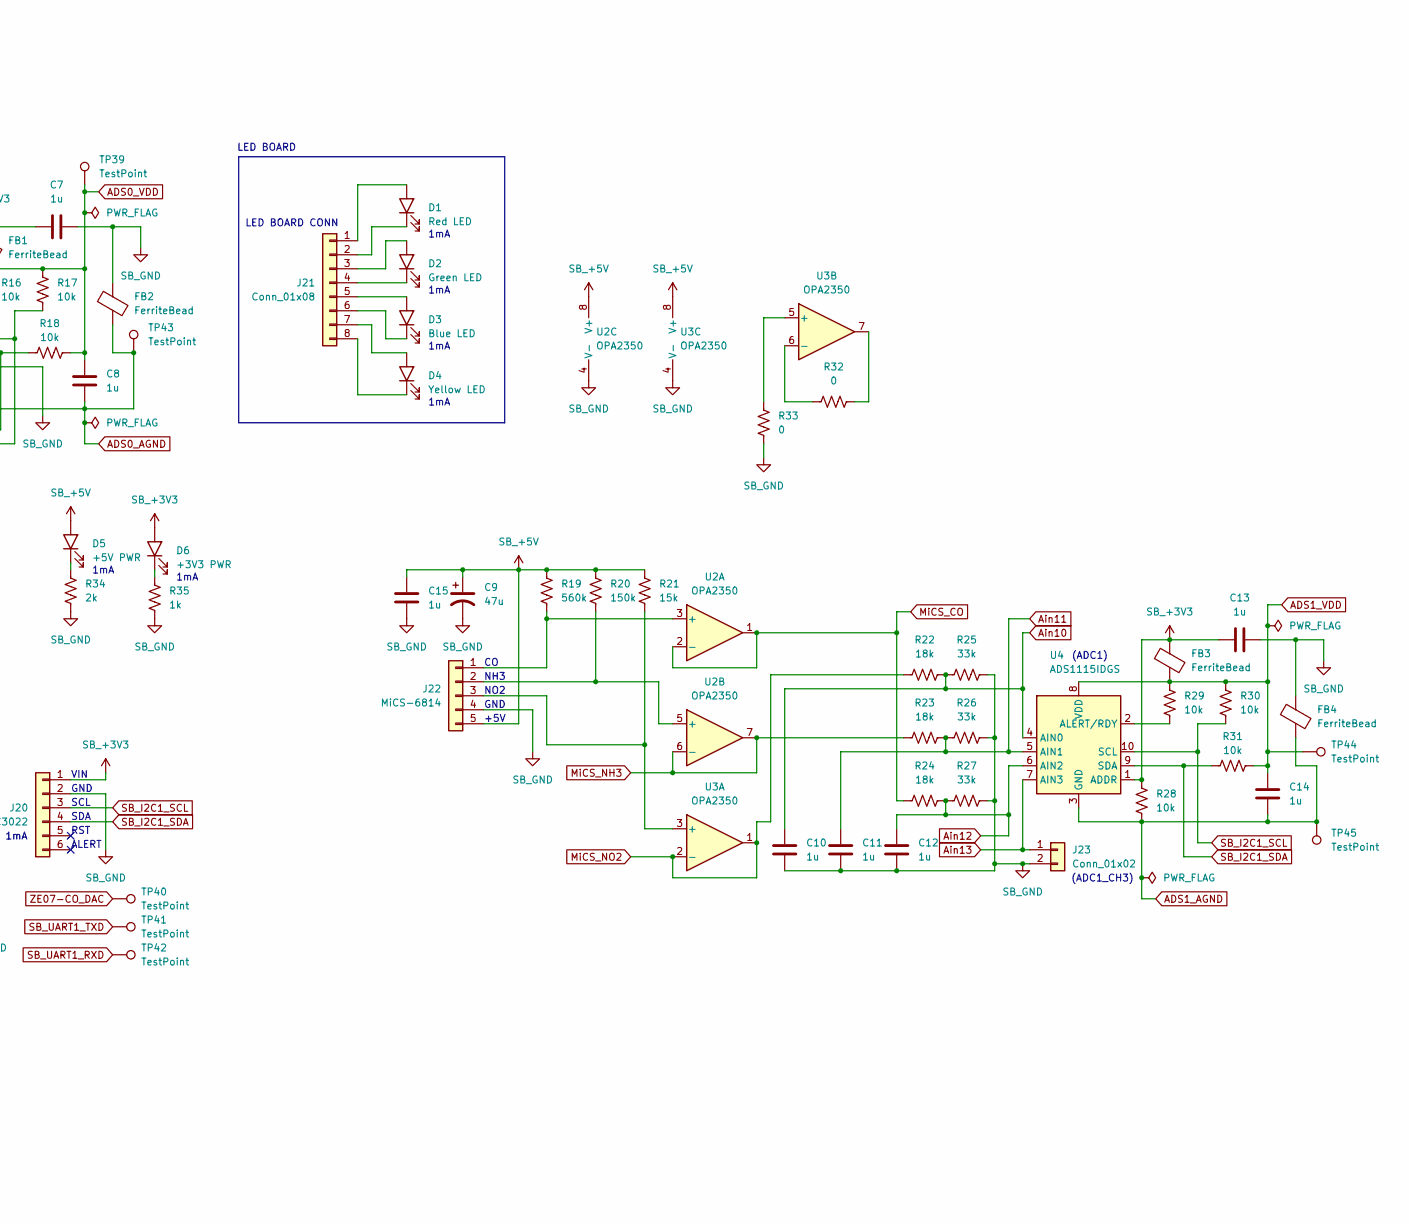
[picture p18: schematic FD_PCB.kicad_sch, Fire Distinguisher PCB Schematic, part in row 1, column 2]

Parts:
C1, C2, C3: 220u; CP_Radial_Tantal200mil
C4, C5, C21: 4.7u; CP_Radial_Tantal200mil
C6, C9: 47u; CP_Radial_Tantal200mil
C7, C8, C10, C11, C12, C13, C14, C15: 1u; C_0805_2012Metric
C16: 10u; C_Axial_200mil
C17, C18, C19, C20: 0.1u; C_0805_2012Metric
D1: Red LED; LED_D5.0mm
D2: Green LED; LED_D5.0mm
D3: Blue LED; LED_D5.0mm
D4: Yellow LED; LED_D5.0mm
D5: +5V PWR; LED_D5.0mm
D6: +3V3 PWR; LED_D5.0mm
FB1, FB2, FB3, FB4: FerriteBead; R_0603_1608Metric
J1: Barrel_Jack_Switch; BarrelJack_Wuerth_6941xx301002
J2, J3: Conn_02x12_Odd_Even; PinHeader_2x12_P2.54mm_Vertical
J4: Conn_02x20_Odd_Even; PinHeader_2x20_P2.54mm_Vertical
J5, J13: Conn_02x10_Odd_Even; PinHeader_2x10_P2.54mm_Vertical
J6: Conn_01x07; PinHeader_1x07_P2.54mm_Vertical
J7, J10, J11, J23: Conn_01x02; PinHeader_1x02_P2.54mm_Vertical
J8, J21: Conn_01x08; PinHeader_1x08_P2.54mm_Vertical
J9: Conn_01x16; PinHeader_1x16_P2.54mm_Vertical
J12: Conn_01x02; JST_PH_B2B-PH-K_1x02_P2.00mm_Vertical
J14: MQ-4 Gas Sensor; PinHeader_1x04_P2.54mm_Vertical
J15: MQ-7 Gas Sensor; PinHeader_1x04_P2.54mm_Vertical
J16: MQ-138 Gas Sensor; PinHeader_1x04_P2.54mm_Vertical
J17: KY-026 Flame Sensor; PinHeader_1x04_P2.54mm_Vertical
J18: Conn_01x10; PinHeader_1x10_P2.00mm_Vertical
J19: Conn_01x05; PinHeader_1x05_P2.00mm_Vertical
J20: HDC3022; PinHeader_1x06_P2.54mm_Vertical
J22: MiCS-6814; PinHeader_1x05_P2.54mm_Vertical
M1, M2: Motor_Servo; PinHeader_1x03_P2.54mm_Vertical
R1, R3, R4, R6, R8, R35: 1k; R_0805_2012Metric
R2: 100k; R_0805_2012Metric
R5: 330; R_0805_2012Metric
R7, R34: 2k; R_0805_2012Metric
R9, R10, R11, R22, R23, R24: 18k; R_0805_2012Metric
R12, R13, R14, R25, R26, R27: 33k; R_0805_2012Metric
R15, R16, R17, R18, R28, R29, R30, R31: 10k; R_0805_2012Metric
R19: 560k; R_0805_2012Metric
R20: 150k; R_0805_2012Metric
R21: 15k; R_0805_2012Metric
R32, R33: 0; R_0805_2012Metric
SW1, SW2, SW3: SW_Push; SW_PUSH_6mm
TP1, TP2, TP3, TP4, TP5, TP6, TP7, TP8, TP9, TP10, TP11, TP12, TP13, TP14, TP15, TP16, TP17, TP18, TP19, TP20, TP21, TP22, TP23, TP24, TP25, TP26, TP27, TP28, TP29, TP30, TP31, TP32, TP33, TP34, TP35, TP36, TP37, TP38, TP39, TP40, TP41, TP42, TP43, TP44, TP45, TP46: TestPoint; TestPoint_Loop_D3.50mm_Drill1.4mm_Beaded
U1, U4: ADS1115IDGS; TSSOP-10_3x3mm_P0.5mm
U2, U3: OPA2350; DIP-8_W7.62mm_LongPads

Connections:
+3V3: J2.1, J2.3, J2.5, J4.1, J4.17, J5.7, J5.9
+5V: J4.2, J4.4, J5.1, J5.3, J5.5
+5V_EXT: C1.1, C2.1, C3.1, C6.1, C16.1, C17.1, C18.1, C19.1, C20.1, J1.1, J6.1, J7.1, J10.1, M1.2 (+), M2.2 (+), TP4.1
ADS0_AGND: C8.2, FB2.2, R15.2, TP43.1, U1.3 (GND)
ADS0_VDD: C8.1, FB1.2, R16.1, R17.1, R18.2, TP39.1, U1.8 (VDD)
ADS1_AGND: C14.2, FB4.2, R28.2, TP45.1, U4.3 (GND)
ADS1_VDD: C14.1, FB3.2, R29.1, R30.1, R31.2, TP44.1, U4.8 (VDD)
Ain00: R9.1, R12.1, TP20.1, U1.4 (AIN0)
Ain01: R10.1, R13.1, TP21.1, U1.5 (AIN1)
Ain02: R11.1, R14.1, TP22.1, U1.6 (AIN2)
Ain03: J17.1, TP23.1, TP29.1, U1.7 (AIN3)
Ain10: C10.1, R22.1, R25.1, TP24.1, U4.4 (AIN0)
Ain11: C11.1, R23.1, R26.1, TP25.1, U4.5 (AIN1)
Ain12: C12.1, R24.1, R27.1, TP26.1, U4.6 (AIN2)
Ain13: J23.1, TP27.1, U4.7 (AIN3)
EXT_GND: C1.2, C2.2, C3.2, C6.2, C16.2, C17.2, C18.2, C19.2, C20.2, J1.2, J4.6, J6.2, J7.2, J10.2, M1.3 (-), M2.3 (-), R2.1, TP8.1
GND: J2.2, J2.4, J2.6, J2.8, J2.10, J2.12, J2.14, J2.16, J2.18, J2.20, J2.22, J2.24, J4.9, J4.14, J4.20, J4.25, J4.30, J4.34, J4.39, J5.2, J5.4, J5.6, J5.8, J5.10, J5.12, J5.14, J5.16, J5.18, J5.20, TP11.1
GPIO01: J2.15, J4.29
GPIO07: J4.32, M1.1 (PWM)
GPIO09: J2.19, J4.7
GPIO11: J2.17, J4.31
GPIO12: J4.15, J5.19
GPIO13: J4.33, M2.1 (PWM)
I2C0_SCL: J4.28
I2C0_SDA: J4.27
I2C1_SCL: J4.5, J5.17
I2C1_SDA: J4.3, J5.15
I2S0_DIN: J4.38
I2S0_DOUT: J4.40, J6.5
I2S0_FS: J4.35, J6.7
I2S0_SCK: J4.12, J6.6
LED_BLUE+: J8.5, R6.2
LED_BLUE-: J8.6, J8.7, J13.19, TP15.1
LED_GREEN+: C7.1, C13.1, C21.1, D6.2 (A), FB1.1, FB3.1, J8.3, J13.7, J13.9, J17.3, J20.1, R6.1, R28.1, TP16.1, U4.1 (ADDR)
LED_GREEN-: J8.4, R8.2
LED_RED+: C4.1, C5.1, C9.1, C15.2, D5.2 (A), J8.1, J13.1, J13.3, J13.5, J14.1, J15.1, J16.1, J18.1, J22.5, R19.1, R20.1, R21.1, TP17.1, U2.8 (V+), U3.8 (V+)
LED_RED-: J8.2, R7.2
LED_YELLOW-: J8.8, R5.2
MQ-4_AO: J14.4, R9.2, TP33.1
MQ-7_AO: J15.4, R10.2, TP34.1
MQ-138_AO: J16.3, R11.2, TP28.1
MiCS_CO: R24.2, TP30.1, U2.1, U2.2 (-)
MiCS_NH3: R23.2, TP31.1, U2.6 (-), U2.7
MiCS_NO2: R22.2, TP32.1, U3.1, U3.2 (-)
unnamed: D1.2 (A), J21.1
unnamed: D1.1 (K), J21.2
unnamed: D2.2 (A), J21.3
unnamed: D2.1 (K), J21.4
unnamed: D3.2 (A), J21.5
unnamed: D3.1 (K), J21.6
unnamed: D4.2 (A), J21.7
unnamed: D4.1 (K), J21.8
unnamed: D5.1 (K), R34.2
unnamed: D6.1 (K), R35.2
unnamed: J6.4, R2.2
unnamed: J11.1, J12.1
unnamed: J11.2, J12.2
unnamed: J22.1, R19.2, U2.3 (+)
unnamed: J22.2, R20.2, U2.5 (+)
unnamed: J22.3, R21.2, U3.3 (+)
unnamed: R32.1, U3.7
unnamed: R16.2, U1.2 (ALERT/RDY)
unnamed: R33.2, U3.5 (+)
unnamed: R32.2, U3.6 (-)
unnamed: R29.2, U4.2 (ALERT/RDY)
SB_GND: C4.2, C5.2, C7.2, C9.2, C10.2, C11.2, C12.2, C13.2, C15.1, C21.2, FB2.1, FB4.1, J13.2, J13.4, J13.6, J13.8, J13.10, J13.12, J13.14, J13.16, J13.18, J13.20, J14.2, J15.2, J16.4, J17.2, J18.2, J19.5, J20.2, J22.4, J23.2, R5.1, R7.1, R8.1, R12.2, R13.2, R14.2, R15.1, R25.2, R26.2, R27.2, R33.1, R34.1, R35.1, TP18.1, TP19.1, TP35.1, TP36.1, U1.1 (ADDR), U2.4 (V-), U3.4 (V-)
SB_I2C1_SCL: J13.17, J20.3, R18.1, R30.2, TP37.1, U1.9 (SDA), U4.10 (SCL)
SB_I2C1_SDA: J13.15, J20.4, R17.2, R31.1, TP38.1, U1.10 (SCL), U4.9 (SDA)
SB_UART1_RXD: J13.13, J18.9, TP42.1
SB_UART1_TXD: J13.11, J18.8, TP41.1
SPI0_CS0: J2.13, J4.24
SPI0_CS1: J4.26
SPI0_MISO: J2.9, J4.21
SPI0_MOSI: J2.11, J4.19
SPI0_SCK: J2.7, J4.23
SPI1_CS0: J2.21, J4.18
SPI1_CS1: J2.23, J4.16
SPI1_MISO: J4.22
SPI1_MOSI: J4.37
SPI1_SCK: J4.13
UART1_CTS: J4.36
UART1_RTS: J4.11
UART1_RXD: J4.10, J5.13
UART1_TXD: J4.8, J5.11
UI_+3V3: J3.1, J3.3, J3.5, J9.2, J9.15, SW1.2, SW2.2, SW3.2, TP1.1
UI_GND: J3.2, J3.4, J3.6, J3.8, J3.10, J3.12, J3.14, J3.16, J3.18, J3.20, J3.22, J3.24, J9.1, J9.16, R1.1, R3.1, R4.1, TP9.1, TP46.1
UI_GPIO01: J3.15, J9.6, TP10.1
UI_GPIO09: J3.19, R3.2, SW2.1, TP5.1
UI_GPIO11: J3.17, J9.7, TP2.1
UI_SPI0_CS0: J3.13, J9.10, TP7.1
UI_SPI0_MISO: J3.9, TP12.1
UI_SPI0_MOSI: J3.11, J9.8, TP14.1
UI_SPI0_SCK: J3.7, J9.9, TP13.1
UI_SPI1_CS0: J3.21, R1.2, SW1.1, TP6.1
UI_SPI1_CS1: J3.23, R4.2, SW3.1, TP3.1
ZE07-CO_DAC: J18.6, TP40.1

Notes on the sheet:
1mA
24-Trace Ribbon Cable
3W 4Ω Speaker
NH3
VCC
10mA?
20-Trace Ribbon Cable
GND
JETSON HEADER BOARD
MAX98357 Vout
JETSON ORIN NANO 40 PIN HEADER CONN
SCL
VIN
SDA
Winsen ZE07-CO Module
MAX98357A Breakout
(ADC1_CH3)
(ADC0)
JST-PH-2
GAS SENSOR ARRAY CIRCUIT
USER HARDWARE LEDS AND SWITCHES
ST7735R LCD
150mA
SENSOR BOARD
100mA
LED BOARD CONN
ALERT
10mA
180mA
JETSON 40-PIN BREAKOUT
(ADC1)
Note: This footprint has pin spacings smaller than 2.54mm!
LCD CONNECTIONS
LED BOARD
NO2
RST
USER INTERFACE BOARD
+5V
SEN0219 PWR

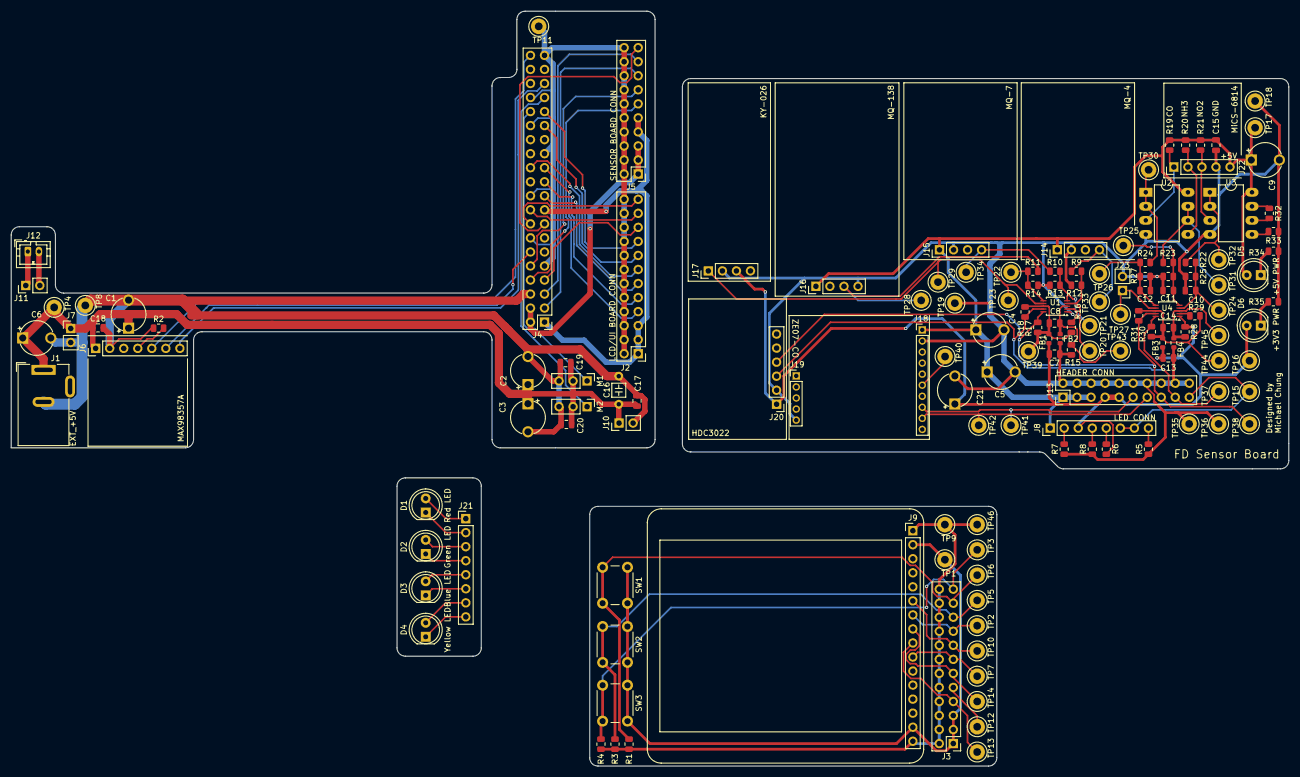
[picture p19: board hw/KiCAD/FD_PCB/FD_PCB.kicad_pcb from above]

Board: 2 copper layers, 231.2 x 136.6 mm, 144 parts (0 on the bottom side), 87 nets.

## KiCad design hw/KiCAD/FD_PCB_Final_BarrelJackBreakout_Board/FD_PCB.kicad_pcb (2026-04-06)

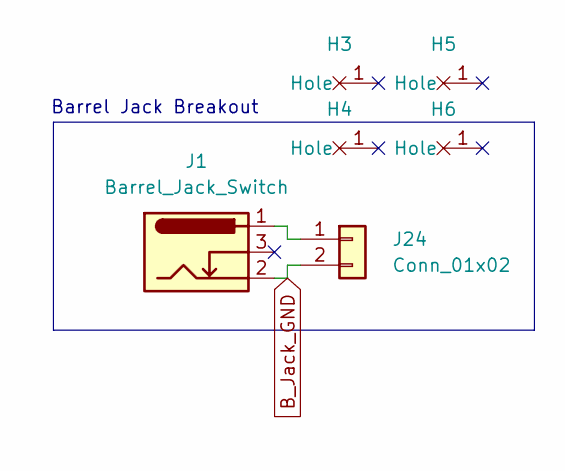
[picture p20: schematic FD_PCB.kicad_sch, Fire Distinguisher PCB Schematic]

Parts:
H3, H4, H5, H6: MountingHole_4_40
J1: Barrel_Jack_Switch; BarrelJack_Wuerth_6941xx301002
J24: Conn_01x02; PinHeader_1x02_P2.54mm_Vertical

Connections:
B_Jack_GND: J1.2, J24.2
unnamed: J1.1, J24.1

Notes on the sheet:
Barrel Jack Breakout

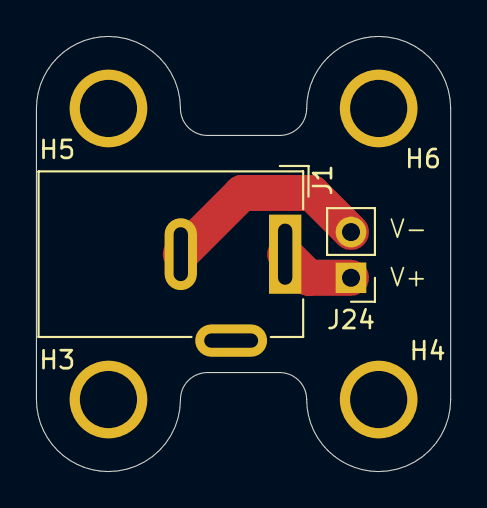
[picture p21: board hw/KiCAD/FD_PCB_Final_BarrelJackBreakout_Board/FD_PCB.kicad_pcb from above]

Board: 2 copper layers, 23.0 x 24.2 mm, 6 parts (0 on the bottom side), 2 nets.

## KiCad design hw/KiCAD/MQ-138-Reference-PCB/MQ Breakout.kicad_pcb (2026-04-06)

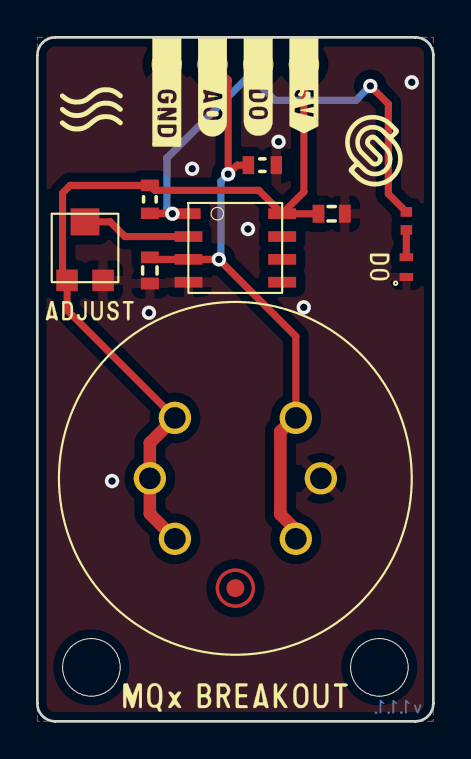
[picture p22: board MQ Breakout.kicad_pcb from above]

Board: 2 copper layers, 22.0 x 38.0 mm, 13 parts (1 on the bottom side), 6 nets.

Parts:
C1, C2: 0.1uF; 0603C
D1: purple; 0402LED
FD1: FIDUCIAL; FIDUCIAL_23
H1, H2: HOLE_3.2mm
K1: HEADER_MALE_4X1
R1, R3: 10k; 0603R
R2: TC33X-2-103E; tc33x-2-103e
R4: 2k2; 0402R
U1: MQ-X; MQ
U2: LM393; SOIC−8

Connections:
5V: C2.2, K1.4, R2.1, R3.2, U1.1 (A), U1.2 (H), U1.3 (A), U2.8 (VCC)
AO: C1.2, K1.2, R1.2, U1.4 (B), U1.6 (B), U2.3 (1_IN+)
D0: K1.3, R3.1, R4.1, U2.1 (1_OUT)
GND: C1.1, C2.1, D1.2 (K), K1.1, R1.1, R2.3, U1.5 (H), U2.4 (GND)
unnamed: D1.1 (A), R4.2
POT: R2.2, U2.2 (1_IN-)

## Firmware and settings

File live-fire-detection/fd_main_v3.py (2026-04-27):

# Fire Distinguisher Main Program
# 3/9/26

# Written Michael Chung

import os
import time
import builtins
import inspect
import pathlib
import threading
import argparse

# Override prints for cleaner logging across our modules
orig_print = builtins.print
PROJECT_ROOT = pathlib.Path(__file__).resolve().parent
def tagged_print(*args, **kwargs):
    frame = inspect.currentframe().f_back
    try:
        file = frame.f_globals.get("__file__")

        if file:
            path = pathlib.Path(file).resolve()

            if PROJECT_ROOT in path.parents or path == PROJECT_ROOT:
                tag = path.stem
                thread = threading.current_thread().name
                orig_print(f"[{tag}:{thread}]", *args, **kwargs)
                return
    finally:
        del frame
    orig_print(*args, **kwargs)
builtins.print = tagged_print

# Do the rest of custom imports here
import constants
import datarecorder
from peripherals.cameras import IRCamera
from peripherals.sensor_suite import SensorSuite
from utilities.fps_tracker import FPSTracker
from utilities.key_handler import TerminalKeyWatcher, poll_quit_key
from utilities.single_instance import SingleInstance
from utilities.web_preview import generate_colorbar_png
from telemetry.telemetry_wrapper import TelemetryWrapper
from servo.fire_tracker_backup import FireTracker, TrackerState
from servo.pan_tilt_tracking import (          # constants only — no factory fns
    PAN_PIN,  TILT_PIN,
    PAN_LIMITS, TILT_LIMITS,
    FRAME_W,  FRAME_H,
    HFOV_DEG, VFOV_DEG,
    PAN_KP,   PAN_KI,   PAN_KD,
    TILT_KP,  TILT_KI,  TILT_KD,
    PAN_ERROR_SIGN, TILT_ERROR_SIGN,
)
import real_time_ml_v3 as ml
from audio.soundthread_v2 import ThreadedSoundPlayer
import gas_sensor_model as gas

class FireDistinguisher:

    def __init__(self, args):
        self.args = args
        
        # Init
        self.run_dir = "/home/firedistinguisher/projects/early-fire-detection-classifier/live-fire-detection/" + constants.RECORDINGS_PARENT_DIR
        self.cmap = IRCamera.ColorMap[constants.IR_COLORMAP]
        generate_colorbar_png(os.path.join("utilities/static", "colorbar.png"), IRCamera.COLORMAPS_LIST[self.cmap.value], num_ticks=3)
        self.ir_norm_settings = ("FIXED", 150, 20) # ("MINMAX", 80, 10) (mode, max, min)

        # Sensor Hardware
        sensor_config = {
                "reg_id": constants.REG_CAMERA_DEVICE_ID,
                "ir_id": constants.IR_CAMERA_DEVICE_ID,
                "ir_colormap": self.cmap,
                "ir_norm_settings": self.ir_norm_settings,
                "use_gstreamer": False,
                "gst_tee": False,
                "run_dir": self.run_dir,
                "fps": constants.FPS,
                }
        self.sensorsuite = SensorSuite(sensor_config)

        # Data Recorder / Main GUI Init
        self.dr = datarecorder.DataRecorder(
            run_dir=self.run_dir,
            reg_id = constants.REG_CAMERA_DEVICE_ID,
            ir_id = constants.IR_CAMERA_DEVICE_ID,
            fps = constants.FPS,
            ir_colormap = self.cmap,
            ir_norm_settings = self.ir_norm_settings,
            sensorsuite = self.sensorsuite,
            console_status=False,
            terminal_quit = True,
            view_only = True,
            use_gstreamer = False,
            verbose = False
        )
        self.web = self.dr.get_web_app()

        # Telemetry System
        self.tw = TelemetryWrapper(sensors=self.sensorsuite.get_sensor_objects(), auto_switch=5, debug=True)
        self.tw.start()

        # Machine Learning
        self.vis_path = '/home/firedistinguisher/projects/early-fire-detection-classifier/machine-learning/models/visible_yolov11n/best_rgb.engine'
        self.ir_path = '/home/firedistinguisher/projects/early-fire-detection-classifier/machine-learning/models/infrared_yolov11n/best_ir.engine'
        self.meta_path = '/home/firedistinguisher/projects/early-fire-detection-classifier/machine-learning/models/meta-learner/fire_meta_learner_v2.pkl'
        self.models = ml.initialize_fire_models(vis_path=self.vis_path, ir_path=self.ir_path, meta_path=self.meta_path)

        # Gas sensor
        self.gas_init_calibration_counter = 0
        self.calibration_samples = []
        self.gas_detect = " | not calibrated"
        # Audio
        self.player = ThreadedSoundPlayer()
        ThreadedSoundPlayer.set_main_player(self.player)
        
        # Pan-Tilt Mount PID Controllers
        self.tracker = FireTracker(
            pan_pin=PAN_PIN,
            tilt_pin=TILT_PIN,
            pan_limits=PAN_LIMITS,
            tilt_limits=TILT_LIMITS,
            frame_w=FRAME_W,
            frame_h=FRAME_H,
            hfov_deg=HFOV_DEG,
            vfov_deg=VFOV_DEG,
            pan_kp=PAN_KP,   pan_ki=PAN_KI,   pan_kd=PAN_KD,
            tilt_kp=TILT_KP, tilt_ki=TILT_KI, tilt_kd=TILT_KD,
            scan_speed=1.5,
            track_speed=3.0,
            pan_sweep_time=4.0,
            track_loss_timeout=3.0,     # Time to wait after losing target before declaring "lost" and resuming scan
            scan_resume_delay=3.0,      # Time to wait after losing target before resuming scan   
            fire_coverage_min=0.0,
            fire_coverage_max=0.2,
            pan_error_sign=PAN_ERROR_SIGN,
            tilt_error_sign=TILT_ERROR_SIGN,
            on_fire_acquired=self._cb_fire_acquired,
            on_fire_lost=self._cb_fire_lost,
            debug=True,
        )

    def _cb_fire_acquired(self) -> None:
        # Runs in tracker callback asyncronously from main tick thread 
        print("Fire acquired - target detected. Stopping scan and tracking.")
        self.player.play(
            "/home/firedistinguisher/projects/early-fire-detection-classifier/live-fire-detection/audio/library/discord_join_sfx.wav",
            volume=0.00,
        )
 
    def _cb_fire_lost(self) -> None:
        # Runs in tracker callback asyncronously from main tick thread
        print("Fire lost - target no longer detected. Resuming scan.")


    def _on_tick(self):
        # Perform the following on every 25Hz tick
        # Read Sensors
        snapshot = self.sensorsuite.get_snapshot()
        
        moby_stuff = {
            "adc0_ch0": snapshot.adc.values[0],
            "adc0_ch1": snapshot.adc.values[1],
            "adc0_ch2": snapshot.adc.values[2],
            "adc1_ch0": snapshot.adc.values[4],
            "adc1_ch1": snapshot.adc.values[5],
            "adc1_ch2": snapshot.adc.values[6],
            "hdc_temp": snapshot.hdc3022.temp,
            "hdc_humidity": snapshot.hdc3022.humidity,
            "co2_ppm": snapshot.sen0219.ppm,
            "co_ppm": snapshot.ze07co.ppm
        }

        ############################################################################################################################
        
        # print("calibration_samples length: ", len(self.calibration_samples))
        # print("CALIBRATING GAS SENSORS...PLEASE HOLD (1 minute)")
        cfg = gas.FireDetectorConfig(
        sample_rate_hz=25.0,
        min_calibration_samples=1500,  # 60 seconds at 25 Hz
        )
        
        if self.gas_init_calibration_counter < cfg.min_calibration_samples:    
            self.calibration_samples.append(moby_stuff)
            # time.sleep(1.0 / cfg.sample_rate_hz)
            self.gas_init_calibration_counter += 1
        if self.gas_init_calibration_counter == cfg.min_calibration_samples:         
            print("Done calibrating gas sensors.!!!!!!!!!!!!!!!!!!!!!!!!!!!!!!!!!!!!!!!!!!!!!!!!!!!!!!!!!!!!!!!!!!!!!!!!!!!!!!!!!!!!!!!!!!!!!!!!!!!!!!!!!!!!!!!!!!!!!!!!!!!!!!!!!!!!!!!!!!!!!!!!!!!!!!!!!!!!!!!!!!!!!!!!!!!!!!!!!!!!!!!!!!!!!!!!!!!!!!!!!!!!!!!!!!!!!!!!!!!!!!!!!!!!!!!!!!!!!!!!!!!!!!!!!!!!!!!!!!!!!!!")
            self.gas_init_calibration_counter += 1
            
        if self.gas_init_calibration_counter >= cfg.min_calibration_samples: 
            detector = gas.init_detector(self.calibration_samples, config=cfg)
            result = detector.process_sample(moby_stuff)

            if result.abnormal:
                print("Abnormal Gas Detected!")
                
            else:
                print("Normal")
            
        
        ############################################################################################################################
        
        # Perform ML
        ml_results = ml.process_fused_detection(
            snapshot.reg.frame,
            snapshot.ir.frame,
            snapshot.ir.temp_frame, 
            self.models,
            returnAnnotatedImg=False
        )
        min_temp, max_temp, avg_temp, center_temp  = self.sensorsuite.get_sensor_objects().ir_camera.get_temp_stats()
        #self.web.set_fire_subtext("Hello World!" + " Min temp =" + str(min_temp) + " Max temp = " + str(max_temp) + " Avg temp = " + str(avg_temp) + " Center temp = " + str(center_temp))
        self.web.set_fire_subtext(f"Counter: {self.gas_init_calibration_counter}   {self.gas_detect}")
        # Pass ML results to Web Stream
        self.web.set_fire_detected(ml_results["meta_decision"]["fire_detection_boolean"])
        self.web.update_ml_results(ml_results)
        
        #print(ml_results["raw_detections"]["visible"])
        #print(ml_results["raw_detections"]["infrared"])      
        
        # Update GUI
        self.dr.on_tick(snapshot, ml_results)    
    
        # Pan-Tilt Tracking: pass ml results to tracker and update pan-tilt angles accordingly
        self.tracker.update(ml_results)
      
    def program_start(self):
        # Main clock
        period = 1.0 / constants.FPS
        next_time = time.perf_counter()

        self.running = True
        while self.running:
            now = time.perf_counter()
            
            # Regulate to 25 Hz - comment out to go as fast as possible
            if now < next_time:
                time.sleep(next_time - now)
                continue

            # ----- detect latency lateness -----
            lateness = now - next_time

            if lateness > period:
                skipped = int(lateness // period)
                # print(
                #     f"WARNING: main loop late by {lateness*1000:.1f} ms "
                #     f"(skipped {skipped} tick{'s' if skipped > 1 else ''})"
                # )

                # reset schedule
                next_time = now

            self._check_terminal_key()
            if not self.running:
                break

            self._on_tick()
            next_time += period

    def _check_terminal_key(self):
        if poll_quit_key():
            print("\nQuitting...")
            #if not self.view_only: # if not self.view_only
            #    print("Saving Data and Recordings...\n")
            #else:
            #    print()

            print() # if the above is uncommented, this was the else condition print, so must be removed when uncommenting.
            self.stop_and_close()

    def stop_and_close(self):
        # Cleanup
        if not hasattr(self, "running"):
            print("Trying to stop, but self.running is None! Perhaps the program has not started yet?")
        if not self.running:
            return
        self.running = False

        # Other cleanup
        self.dr.stop_and_close()
        self.tw.stop()

        # cancels timers, callbacks, and halts mount
        self.tracker.shutdown(center=True)  
        
        self.player.close()

        time.sleep(1) # Wait for sensor consumers to stop

        self.sensorsuite.stop_and_close()
def main():

    # Arg parser
    p = argparse.ArgumentParser(description="Main GUI")

    # Only allow one instance of this to run
    lock = SingleInstance("/tmp/jetson_main-program.lock")
    try:
        lock.acquire()
    except RuntimeError as e:
        print()
        print(str(e))
        print("Another instance of this script is already running!\n")
        raise SystemExit(1)
    
    fd = FireDistinguisher(p.parse_args())

    with TerminalKeyWatcher():
        fd.program_start()

    print("Closing App.\n")

if __name__ == "__main__":
    main()

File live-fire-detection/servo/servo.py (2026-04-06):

import Jetson.GPIO as GPIO
import time
import threading
import math

class Servo:
    # SG90 Spec: 0.12s / 60 degrees -> ~500 degrees / second
    SG90_MAX_SPEED_DEG_PER_SEC = 500.0

    def __init__(
        self,
        pin,
        frequency=50,
        min_duty=2.5,
        max_duty=12.5,
        min_angle=0.0,
        max_angle=180.0,
        transition_type='instant',
        transition_speed=1.0,
        min_limit=None,
        max_limit=None
    ):
        self.pin = pin
        self.frequency = frequency
        self.min_duty = min_duty
        self.max_duty = max_duty
        self.min_angle = min_angle
        self.max_angle = max_angle
        self.current_duty = 0.0

        # Limits (Software restrictions)
        self.min_limit = min_limit if min_limit is not None else min_angle
        self.max_limit = max_limit if max_limit is not None else max_angle

        # Movement State
        self.current_angle = self.min_limit
        self.target_angle = self.min_limit
        self._move_start_angle = self.min_limit
        self.transition_type = transition_type
        self.transition_speed = transition_speed

        self._lock = threading.Lock()

        # PWM State Management
        self._pwm_is_active = False
        self._completion_time = 0.0

        # Setup Hardware
        GPIO.setup(self.pin, GPIO.OUT)
        self.pwm = GPIO.PWM(self.pin, self.frequency)

        # Initialize with 0 duty cycle (OFF) to prevent jitter at startup
        self.pwm.start(0.0)

        # Start Movement Thread
        self._running = True
        self._worker_thread = threading.Thread(target=self._move_worker, daemon=True)
        self._worker_thread.start()

    def angle_to_duty(self, angle):
        angle = max(self.min_angle, min(self.max_angle, angle))
        span_angle = self.max_angle - self.min_angle
        span_duty = self.max_duty - self.min_duty
        duty = self.min_duty + (angle - self.min_angle) * span_duty / span_angle
        self.current_duty = duty
        return duty

    def set_limits(self, min_limit, max_limit):
        if min_limit >= max_limit:
            raise ValueError("Min limit must be less than max limit")
        min_limit = max(self.min_angle, min_limit)
        max_limit = min(self.max_angle, max_limit)

        with self._lock:
            self.min_limit = min_limit
            self.max_limit = max_limit
            if self.target_angle < min_limit:
                self.target_angle = min_limit
            elif self.target_angle > max_limit:
                self.target_angle = max_limit

    def set_transition(self, transition_type):
        self.check_transition(transition_type)
        with self._lock:
            self.transition_type = transition_type

    def check_transition(self, transition_type):
        valid_transitions = ['instant', 'linear', 's-curve', 'ease-out-quad', 'ease-in-out-quad', 'sine']
        if transition_type not in valid_transitions:
            raise ValueError(f"Invalid transition type. Valid options are: {valid_transitions}")

    def set_speed(self, speed: float | int):
        with self._lock:
            self.transition_speed = speed

    def set_angle(self, angle, transition_type=None, speed=None):
        """
        Public API to set a new target angle.
        Non-blocking - returns immediately.
        """
        angle = max(self.min_limit, min(self.max_limit, angle))

        with self._lock:
            self._move_start_angle = self.current_angle
            self.target_angle = angle
            if transition_type is not None:
                self.transition_type = transition_type
            if speed is not None:
                self.transition_speed = speed

    def get_angle(self):
        """
        Public API to get the current angle.
        This does not return the targeted angle,
        yet it returns the last set angle INTERNALLY.
        """
        with self._lock:
            angle = self.current_angle
        return angle

    def _start_pwm(self, duty):
        """Starts or updates the PWM signal."""
        if not self._pwm_is_active:
            self.pwm.start(duty)
            self._pwm_is_active = True
        else:
            self.pwm.ChangeDutyCycle(duty)

    def _stop_pwm(self):
        """Stops the PWM signal to prevent jitter."""
        if self._pwm_is_active:
            self.pwm.ChangeDutyCycle(0.0)
            self._pwm_is_active = False

    def _move_worker(self):
        """
        Background thread that handles movement and PWM release.
        """
        while self._running:
            # 1. Read state atomically
            with self._lock:
                start_angle = self.current_angle
                end_angle = self.target_angle
                transition_type = self.transition_type
                speed = self.transition_speed
                move_start_angle = self._move_start_angle

            distance = abs(end_angle - start_angle)

            # 2. Check if we need to move
            if distance > 0.1:
                # Estimate how long this specific step or move will take.
                software_speed_deg_sec = speed * 50.0

                if transition_type == 'instant':
                    effective_speed = self.SG90_MAX_SPEED_DEG_PER_SEC
                else:
                    estimated_avg_speed = software_speed_deg_sec * 0.6
                    effective_speed = min(estimated_avg_speed, self.SG90_MAX_SPEED_DEG_PER_SEC)

                estimated_duration = (distance / effective_speed) + 0.05
                self._completion_time = time.time() + estimated_duration

                # Calculate next step
                next_angle = self._calculate_next_angle(
                    start_angle, end_angle, transition_type, speed, move_start_angle
                )

                # Update state
                with self._lock:
                    self.current_angle = next_angle

                # Apply PWM
                duty = self.angle_to_duty(next_angle)
                self._start_pwm(duty)

            else:
                # 3. At target - stop PWM to prevent jitter
                #self._stop_pwm()

                if time.time() > self._completion_time:
                    self._stop_pwm()

            # Loop frequency matched to servo PWM frequency
            time.sleep(1 / 500.0)

    def _calculate_next_angle(self, start_angle, end_angle, transition_type, speed, move_start_angle):
        direction = 1 if end_angle > start_angle else -1
        error = abs(end_angle - start_angle)
        reduction_factor = 2 #max(1.0, min(8.0, speed * 0.2)) 

        if transition_type == 'instant':
            return end_angle

        elif transition_type == 'linear':
            step = speed * direction
            step = step / reduction_factor
            step = math.copysign(max(abs(step), 0.5), direction)
            return end_angle if abs(step) > error else start_angle + step
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

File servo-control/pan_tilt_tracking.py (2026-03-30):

"""
pan_tilt_tracking.py
====================
Single-threaded fire-tracking driver for the Smart Autonomous Early Fire
Detection System (Jetson Orin Nano).

Architecture
------------
One tight main loop drives everything sequentially:

    1. Grab visible + IR frames from your camera pipeline.
    2. Run process_fused_detection() → results dict.
    3. ObjCenter parses the box from meta_decision.
    4a. Fire detected  → stop scan, PID centres the mount on the fire box.
    4b. No fire        → start/resume raster scan.

No multiprocessing is used — the detection pipeline already runs fast enough
that a single thread is clean and easy to reason about.

TODOs are clearly marked.  Fill them in before running.
"""

# ── Standard imports ──────────────────────────────────────────────────────────
import math
import signal
import sys
import time

# ── Project imports ───────────────────────────────────────────────────────────
from CameraMount2Axis import CameraMount2Axis
from objcenter import ObjCenter
from pid import PID

# TODO: replace with your actual detection module import
# from your_detection_module import process_fused_detection, load_models

# =============================================================================
# Configuration — edit these constants to match your hardware / preferences
# =============================================================================

# ── Camera resolution (visible sensor) ───────────────────────────────────────
FRAME_W = 640   # pixels
FRAME_H = 480   # pixels

# ── Camera field of view ──────────────────────────────────────────────────────
# From camera datasheet: 56° × 42° (horizontal × vertical).
# The angular error formula requires the HALF-FOV angle (θ) in radians:
#
#   φ = tan⁻¹( 2x · tan(θ) / b )
#
# where x  = pixel offset from frame centre (signed),
#       θ  = half-FOV for that axis (radians),
#       b  = total frame dimension in pixels for that axis,
#       φ  = angular displacement from boresight (degrees, output).
#
# Source: https://stackoverflow.com/a/tagged/camera-fov (right-triangle derivation)
HFOV_DEG = 56.0                                # full horizontal FOV (degrees)
VFOV_DEG = 42.0                                # full vertical   FOV (degrees)
HALF_HFOV_RAD = math.radians(HFOV_DEG / 2.0)  # θ for pan  axis
HALF_VFOV_RAD = math.radians(VFOV_DEG / 2.0)  # θ for tilt axis

# ── GPIO pins (Jetson BOARD numbering) ───────────────────────────────────────
PAN_PIN  = 33
TILT_PIN = 35

# ── Mount angle limits (degrees, 0–180) ──────────────────────────────────────
PAN_LIMITS  = (0.0,  180.0)   # (min, max)
TILT_LIMITS = (90.0, 180.0)   # (min, max)

# ── PID gains ────────────────────────────────────────────────────────────────
# With angular error, kP ≈ 1.0 is a reasonable starting point.
# A kP of 1.0 means a 10° angular offset produces a 10° servo correction.
#
# Tuning steps:
#   1. Set kI = kD = 0.  Increase kP until the mount oscillates steadily,
#      then halve kP.
#   2. Increase kI until steady-state offset disappears.
#   3. Increase kD until overshoot is damped.
PAN_KP,  PAN_KI,  PAN_KD  = 1.0, 0.0, 0.0
TILT_KP, TILT_KI, TILT_KD = 1.0, 0.0, 0.0

# ── Error sign convention ─────────────────────────────────────────────────────
# Defines the physical direction a positive angular error maps to.
#
# PAN_ERROR_SIGN:
#   +1 → fire to the RIGHT means pan angle should INCREASE.
#   -1 → invert if your mount pans the opposite direction.
#
# TILT_ERROR_SIGN:
#   -1 → fire BELOW centre means tilt angle should DECREASE.
#   +1 → invert if your mount tilts the opposite direction.
PAN_ERROR_SIGN  = +1
TILT_ERROR_SIGN = -1

# ── Raster scan parameters ────────────────────────────────────────────────────
SCAN_DURATION  = 45.0   # seconds per full sweep (adjust 30–60)
SCAN_TILT_ROWS = 5      # number of tilt levels in the grid
SCAN_PAN_COLS  = 9      # number of pan stops per row

# =============================================================================
# Angular error helper
# =============================================================================

def pixel_to_angle(pixel_offset: float, half_fov_rad: float, frame_dim: int) -> float:
    """
    Convert a signed pixel offset from frame centre into an angular
    displacement from the camera center, using the exact right-triangle
    derivation.

    Formula:    φ = tan⁻¹( 2x · tan(θ) / b )

    Args:
        pixel_offset:  Signed pixel distance from frame centre.
                       Positive → right / down; negative → left / up.
        half_fov_rad:  Half the field-of-view for this axis, in radians.
                       e.g. math.radians(56/2) for horizontal.
        frame_dim:     Total frame size in pixels for this axis (b in formula).

    Returns:
        Angular displacement φ in degrees.
        Range: (−half_fov_deg, +half_fov_deg)
    """
    return math.degrees(
        math.atan2(2.0 * pixel_offset * math.tan(half_fov_rad), frame_dim)
    )


# =============================================================================
# Initialisation
# =============================================================================

def build_mount() -> CameraMount2Axis:
    return CameraMount2Axis(
        pan_pin=PAN_PIN,
        tilt_pin=TILT_PIN,
        transition_type='instant',       # instant for PID; scan uses same
        transition_speed=5.0,          # not used for 'instant', but required
        pan_limits=PAN_LIMITS,
        tilt_limits=TILT_LIMITS,
        update_rate_hz=50.0
    )


def build_pids():
    pid_pan  = PID(kP=PAN_KP,  kI=PAN_KI,  kD=PAN_KD)
    pid_tilt = PID(kP=TILT_KP, kI=TILT_KI, kD=TILT_KD)
    pid_pan.initialize()
    pid_tilt.initialize()
    return pid_pan, pid_tilt


def signal_handler(sig, frame):
    """Graceful Ctrl-C shutdown — called from the except block below too."""
    print("\n[INFO] Interrupt received — shutting down.")
    sys.exit(0)


# =============================================================================
# Main loop
# =============================================================================
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

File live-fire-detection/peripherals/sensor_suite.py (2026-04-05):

# Sensor Package Class
# Use this to get access to sensors


import os
import numpy as np
import time
import cv2
import threading
from dataclasses import dataclass, field
from typing import Optional, List

from peripherals.cameras import Camera, IRCamera
from peripherals.adc import ADC
from peripherals.hdc3022 import HDC3022
from peripherals.uart_sensors import SEN0219, ZE07CO
from peripherals.uart_sensors import CO2Sample as CO2Packet


# ----------------------------
# Thread-safe “latest value” holders
# ----------------------------
@dataclass
class FramePacket:
    t: float
    frame: Optional[np.ndarray]

class LatestFrame:
    def __init__(self):
        self._lock = threading.Lock()
        self._pkt = FramePacket(t=0.0, frame=None)

    def set(self, frame: np.ndarray, t: float):
        with self._lock:
            self._pkt = FramePacket(t=t, frame=frame)

    def get(self) -> FramePacket:
        with self._lock:
            return self._pkt

@dataclass
class TempHumPacket:
    t: float
    temp: Optional[float] = None
    humidity: Optional[float] = None

class LatestTempHum:
    def __init__(self):
        self._lock = threading.Lock()
        self._pkt = TempHumPacket(t=0.0, temp=None, humidity=None)
    def set(self, t: float, temp=None, humidity=None):
        with self._lock:
            self._pkt = TempHumPacket(t=t, temp=temp, humidity=humidity)
    def get(self) -> TempHumPacket:
        with self._lock:
            return self._pkt

@dataclass
class IrFramePacket:
    t: float
    frame: Optional[np.ndarray]
    temp_frame: Optional[np.ndarray]
    ema_frame: Optional[np.ndarray] = None
    ema_temp_frame: Optional[np.ndarray] = None
    tmin: Optional[float] = None
    tmax: Optional[float] = None
    tavg: Optional[float] = None
    tcenter: Optional[float] = None
    colormap: Optional[str] = None  # e.g. "JET"
    sat_above: Optional[float] = None
    sat_below: Optional[float] = None
    norm_max: Optional[float] = None
    norm_min: Optional[float] = None
    norm_mode: Optional[str] = None

class LatestIRFrame:
    def __init__(self):
        self._lock = threading.Lock()
        self._pkt = IrFramePacket(t=0.0, frame=None, temp_frame=None)

    def set(self, frame: np.ndarray, t: float,
            temp_frame: np.ndarray, # Absolute temperatures
            ema_frame: np.ndarray = None,
            ema_temp_frame: np.ndarray = None,
            tmin: Optional[float] = None,
            tmax: Optional[float] = None,
            tavg: Optional[float] = None,
            tcenter: Optional[float] = None,
            colormap: Optional[str] = None,
            sat_below: Optional[float] = None,
            sat_above: Optional[float] = None,
            norm_min: Optional[float] = None,
            norm_max: Optional[float] = None,
            norm_mode: Optional[float] = None):
        with self._lock:
            self._pkt = IrFramePacket(
                t=t, frame=frame,
                temp_frame=temp_frame,
                ema_frame=ema_frame, ema_temp_frame=ema_temp_frame,
                tmin=tmin, tmax=tmax, tavg=tavg, tcenter=tcenter,
                colormap=colormap,
                sat_above=sat_above, sat_below=sat_below, norm_max=norm_max, norm_min=norm_min,
                norm_mode=norm_mode
            )
    def get(self) -> IrFramePacket:
        with self._lock:
            return self._pkt


@dataclass
class AdcPacket:
    t: float
    values: List[int]   # len 8
    sweep_dt: float

class LatestAdc:
    def __init__(self):
        self._lock = threading.Lock()
        self._pkt = AdcPacket(t=0.0, values=[-1]*8, sweep_dt=0.0)

    def set(self, pkt: AdcPacket):
        with self._lock:
            self._pkt = pkt

    def get(self) -> AdcPacket:
        with self._lock:
            return self._pkt


# CO2Packet imported from peripherals.uart_sensors
class LatestSEN0219:
    def __init__(self):
        self._lock = threading.Lock()
        self._pkt = CO2Packet(t=0.0, ppm=0, raw_hex="0x00", repeated=False)
    def set(self, co2_reading: CO2Packet):
        with self._lock:
            self._pkt = co2_reading
    def get(self) -> CO2Packet:
        with self._lock:
            return self._pkt
# CO2Packet is same format for CO ZE07.
class LatestZE07CO:
    def __init__(self):
        self._lock = threading.Lock()
        self._pkt = CO2Packet(t=0.0, ppm=0, raw_hex="0x00", repeated=False)
    def set(self, co_reading: CO2Packet):
        with self._lock:
            self._pkt = co_reading
    def get(self) -> CO2Packet:
        with self._lock:
            return self._pkt


# ----------------------------
# Workers
# ----------------------------
def camera_worker(cam: Camera, latest: LatestFrame, stop_evt: threading.Event):
    while not stop_evt.is_set():
        cam.update_frames()
        f = cam.get_latest_frame()
        if f is not None:
            latest.set(f, time.perf_counter())

def ir_camera_worker(cam: IRCamera, latest: LatestIRFrame, stop_evt: threading.Event, colormap_name: str):
    while not stop_evt.is_set():
        cam.update_frames()
        f = cam.get_latest_frame()
        if f is None:
            continue
        t = time.perf_counter()
        tmin, tmax, tavg, tcenter = cam.get_temp_stats()  # this method to IRCamera
        norm_min, norm_max, sat_below, sat_above = cam.get_fixed_norm_stats()
        temp_frame = cam.get_raw_thermal_frame()
        ema_frame = cam.get_ema_thermal_bgr()
        ema_temp_frame = cam.get_ema_thermal_temps()
        latest.set(
            frame=f,
            t=t,
            temp_frame=temp_frame,
            ema_frame=ema_frame,
            ema_temp_frame=ema_temp_frame,
            tmin=tmin,
            tmax=tmax,
            tavg=tavg,
            tcenter=tcenter,
            colormap=colormap_name,
            sat_below=sat_below,
            sat_above=sat_above,
            norm_min=norm_min,
            norm_max=norm_max,
            norm_mode=cam.get_norm_mode().value
        )

def adc_worker(adc: ADC, latest: LatestAdc, stop_evt: threading.Event):
    while not stop_evt.is_set():
        t0 = time.perf_counter()
        # vals = []
        # for dev in (0, 1):
        #     for ch in (0, 1, 2, 3):
        #         vals.append(adc.read(dev, ch))
        #adc0_values = adc.read4_once(0)
        #adc1_values = adc.read4_once(1)
        #vals = adc0_values + adc1_values
        adc.update_all()
        vals = adc.get_all_latest()
        t1 = time.perf_counter()
        latest.set(AdcPacket(t=t1, values=vals, sweep_dt=(t1 - t0)))
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

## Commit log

2026-01-29 add txt file test commit from jetson nano
2026-01-29 edit hi from jetson test file
2026-01-29 move all current jetson project files to repo
    [adc.csv, pyvenv.cfg]
2026-01-30 Successful Test of PWM Servo Control on Pin 33
2026-02-02 Untested Servo Mount Class Files
2026-02-02 Untested Servo Mount Control Class
2026-02-04 Update CameraMount2Axis.py
    Bug Fix: Changed Servo to servo.Servo
    [CameraMount2Axis.py]
2026-02-04 Update servo.py
    Feature Addition: Added Several Transition Types to Test
2026-02-04 Update CameraMount2Axis.py
    Bug Fix: Made transition type and transition speed available to CameraMount2Axis class
    [CameraMount2Axis.py]
2026-02-04 Added a command-line test script for the servos
2026-02-04 Added README for servo test file
2026-02-08 update data recording script
    [adc.csv]
2026-02-08 add uart testing scripts
2026-02-08 Bug Fix: Calibrated Servo Control
    -Both Pan and Tilt Servos now have a range of motion of 0-180 degrees
    -Tilt Servo: 0 degrees - UP, 90 degrees - Straight, 180 degrees - Down
    -Pan Servo: 90 degrees - Center
    [CameraMount2Axis.py, servo-manual.py, servo.py]
2026-02-09 Feature: Added Command Line Camera Controller
2026-02-09 fix chartjs issue in data recording script
    [cameras.py]
2026-02-09 Fix: Update Servo Control
    [CameraMount2Axis.py, servo.py]
2026-02-09 AJ: update to do list for servos
2026-02-11 rename uart folder and update uart testing scripts
2026-02-11 remove old uart testing folder name
2026-02-21 Add ZE07 sensor class, succesfully interfaced SEN0219 and ZE07-CO sensors to data collection script
2026-02-21 add ZE07 testing module for uart testing with 40-pin header uart pins
2026-02-23 AJ: Updated gitignore file to exclude recordings
    [adc.csv]
2026-02-23 AJ: Fixed Jitter Issue and added Clamping on Servos
    [CameraMount2Axis.py, camera-controller.py, servo.py]
2026-03-04 fix IR writer latency issue. Added dedicated thread + double buffering
    [record.py]
2026-03-04 fix IR writer latency issue. Switched to uncompressed npz. Added test files. Edit: Keeping test files untracked due to large size
2026-03-07 AJ: Color conversion bug MultiViewDisplay.py
    [MultiViewDisplay.py]
2026-03-07 fix view only run dir
    [cameras.py]
2026-03-09 AJ: Successful implementation of Telemetry Display with threading
2026-03-23 upload KiCAD projects
    [FD_PCB.kicad_pcb, FD_PCB.kicad_sch, FireDistinguisher.kicad_pcb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]
2026-03-24 Created ML modules and fixed warnings in the printing outputs. Updated testing real-time for testing live data streams. -Moby
2026-03-24 update kicad stuff
    [FD_PCB.kicad_sch]
2026-03-29 AJ: Fixing Merge Conflict
    [fused_telemetry_log.csv]
2026-03-29 AJ: Implement Multi-threading to Camera Mount in Prep. for PID implementation
2026-03-30 AJ: First implementation of PID controller without tuning
2026-03-31 AJ: Successful P-controller Track Implementation
2026-03-31 AJ: Added PSD Analysis for Gas Sensors
2026-04-02 Finish schematic and start on PCB design. Much progress.
    [FD_PCB.kicad_pcb, FD_PCB.kicad_sch]
2026-04-04 finish sensor board, lcd board, led board, and header board
    [FD_PCB.kicad_pcb, FD_PCB.kicad_sch]
2026-04-05 finish adding mouting holes and do some prints
    [FD_PCB.kicad_pcb, FD_PCB.kicad_sch, MQ Breakout.kicad_pcb]
2026-04-05 add silkscreen, generate latest print p3-104
    [FD_PCB.kicad_pcb]
2026-04-05 rename with peninsula
    [FD_PCB.kicad_pcb, FD_PCB.kicad_sch]
2026-04-05 update gui and ir camera api for temp frames
2026-04-06 fix header board collision dimensions, add additional mounting hole on header board
    [FD_PCB.kicad_pcb]
2026-04-06 add measurement for H20
    [FD_PCB.kicad_pcb]
2026-04-06 update mounting hole position for H17 and H18
    [FD_PCB.kicad_pcb]
2026-04-06 Decorate Silkscreen
    [FD_PCB.kicad_pcb]
2026-04-06 generate prints
2026-04-06 finalize pcb
    [FD_PCB.kicad_pcb]
2026-04-06 separate boards and generate pcb production gerber files
    [FD_PCB.kicad_pcb, FD_PCB.kicad_sch, bom.csv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]
2026-04-07 fix IR frame issue
    [cameras.py]
2026-04-07 fix typos, fix IR camera frame issue
    [cameras.py]
2026-04-13 Add fd_main_v3 containing refactored fire_tracker class
    Removed the tracking logic from fd_main and placed PID and ObjCenter classes into a comprehensive fire_tracker class. This class builds the servo mount class, PID control loops for each servo, and handles callbacks associated with the state of the fire_tracker. These callbacks are multithreaded to allow fd_main to pass a custom function to help debug issues and/or track the current state of the fire_tracker.
    [fd_main_v3.py]
2026-04-13 AJ: Fix fd_main_v3 pwm frequency
    [CameraMount2Axis.py, camera-controller.py, fd_main_v3.py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]
2026-04-14 AJ: Stablized PI Controller By Adding a Deadzone
    [pid_session_2026-04-13_19-13-01.csv, pid_session_2026-04-13_19-14-36.csv, pid_session_2026-04-13_19-14-48.csv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]
2026-04-15 Pushing updates for AJ. -Moby
    [pid_session_2026-04-13_22-07-02.csv, pid_session_2026-04-13_22-07-18.csv, pid_session_2026-04-13_22-07-36.csv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]
2026-04-19 save copies of device tree overlays
2026-04-19 fix cts pinmux pin name
2026-04-19 try servo controls, add SPI DAC
2026-04-27 AJ: further refinement of controller
    [pid_session_2026-04-15_17-21-13.csv, pid_session_2026-04-15_17-21-36.csv, pid_session_2026-04-15_17-21-50.csv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]
